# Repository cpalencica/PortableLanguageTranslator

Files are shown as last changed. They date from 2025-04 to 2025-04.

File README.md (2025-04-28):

# Portable Language Translator - Engineering Addendum

This document serves as knowledge transfer guide for any potential future teams working on the Portable Language Translator project. It outlines the current state of the project, technical challenges, implementation details and known issues to assist in understanding and further devloping this system.

## Project Overview
The Portable Language Translator is a wearable device that enables real-time translation between spoken languages (currently English, Spanish, Korean) and basic American Sign Langauge (ASL) gestures. The system uses a Raspberry Pi 5, camera, microphone, touch screen and speakers housed in a 3D-printed enclosure with shoulder straps for portability.

## Core Functionality
- **Speech-to-Speech Translation:** Translates between English, Spanish and Korean using Google Cloud APIs
- **ASL Gesture Recognition:** Recognizes 5 ASL gestures ("Hello", "Thank You", "Bathroom", "Help", "Yes") and converts them into speech
- **Two-way Communication:** Enables conversation between ASL users and non-signers

## Repository Structure
This repository is organized into three main folders:
- **sw (Software):** Contains all the software-related code, scripts and documentation. A detailed `README_SOFTWARE.md` specific to the software components can be found inside this folder.
- **hw (Hardware):** Contains all the hardware-related files, schematics and documentation. The hw folder includes its own `README_HARDWARE.md` with hardware-specific details.
- **fw (Firmware):** Contains firmware code and documentation. The fw folder also has a dedicated `README_FIRMWARE.md` explaining the firmware components.

Each subfolder provides its own README that describes the specific components and instructions that relate to that part of the Portable Language Translator.

## Technical Architecture
### Hardware Components
- Raspberry Pi 5
- USB 2.0 Camera
- USB Microphone
- USB Speaker
- Touch Screen
- 5000 mAh battery pack
- 3D-printed enclosure

### Language Translation Pipeline
1. **Audio Capture:** Using USB microphone and WebRTC VAD for speech detection
2. **Speech-to-Text:** Google Cloud Speech-to-Text API
3. **Translation:** Google Cloud Translation API
4. **Text-to-Speech:** Google Cloud Text-to-Speech API
5. **Audio Output:** Through USB speakers

### ASL Recognition Pipeline
1. **Video Capture:** Using USB camera with OpenCV
2. **Hand Landmark Detection:** Using MediaPipe
3. **Gesture Classification:** LSTM model converted to TFLite
4. **Speech Synthesis:** Outputs recognized gesture as spoken words

### User Interface
- Built with PyQt5
- Three main tabs: Translation, WiFi Connection, Settings
- Volume controls and mode toggle (physical buttons)

## Getting Started
### Prerequisites
- Internet Connection (required for cloud based translation APIs)
- Python 3.9+ environment
- Power Source for the Raspberry Pi 5 (exterior battery pack)

### Initial Setup
1. **Power on:** Press the power button on the battery pack once
2. **Connect to WiFi:** Navigate to WiFi tab and connect to a network
3. **Configure Settings:** Set your preferred language options in the Settings tab
4. **Start Translation:** Return to the Translation tab to begin using the device

### Operating Modes
- **Speech Translation Mode**: Speak and the device will detect the language being spoken and translate bidirectionally with the base language set in the Settings tab.
- **ASL Mode:** Press the button on the left side to switch modes. The camera feed will display and detect ASL gestures.

## Technical Gotchas and Known Issues
### Critical Information
- **Internet Dependency:** The speech translation functionality requires an internet connection to use Google Cloud APIs. ASL recognition works offline but with limited vocabulary.
- **Battery Life Constraints:** The device runs for approximately 3.125 hours on a full charge.
- **ASL Recognition Limitations:** The current implementation only recognizes 5 gestures with 80%+ accuracy. Optimal detection distance is 0.67 to 1 meter from camera and the performance degrades significantly past this range.
- **Speech Recognition Limitations:** Works best 0.5-1 meters from microphone and converstational volume is required for reliable operation. Background noise can impact performance.
- **Heat Management:** The Raspberry Pi 5 can get hot during extended use.
- **Water/Moisture Vulnerability:** The device is not waterproof or water-resistant. Keep away from liquids.

### Development Challenges
When extending this project, be aware of these challenges we encountered:
- **LSTM Model Optimization:** Converting the TensorFlow model to TFLite required balancing accuracy with performance. Further optimization might be possible.
- **Latency Management:** Speech translation introduces variable latency (0.34-1.90 seconds) depending on phrase length. ASL recognition has approximately 2.5 seconds of latency.
- **Model Training:** During our second prototype testing, the ASL recognition model was trained on a limited dataset. Ensure there is a significant amount of data for higher recognition accuracy.

### Future Improvements
Based on our experience, these areas would benefit from further development:
- **Expanded ASL Vocabulary:** The current system only recognizes 5 gestures. Training the model on more gestures would increase utility.
- **Offline Translation:** Implementing an on-device translation library would eliminate the need for an internet connection.
- **Environmental Robustness:** Adding more noise cancellation for the microphone and improving camera performance in varied lighting conditions.

## Debugging Tips
### Common Issues and Solutions
- **Device Won't Power On:** Check battery charge level on the external battery pack and verify connections between battery and Raspberry Pi.
- **No Audio Output:** Check volume settings and verify speaker connection.
- **Camera Not Working:** Check USB connection.
- **Slow Performance:** Check CPU temperature and verify proper cooling for the Raspberry Pi 5.

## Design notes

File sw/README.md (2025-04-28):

# Software Modules Overview

## main.py

### Overview
Main.py file serves as the main controller for the Portable Language Translator. It integrates ASL gesture recognition, speech processing, and hardware control. It uses TensorFlow Lite for ASL recognition, MediaPipe for pose detection, and a custom class that uses Google Cloud for speech processing. The system operates in two modes: ASL and Speech. 

### Core Framework and Dependencies
The system integrates multiple key libraries including TensorFlow, MediaPipe, OpenCV, and PyQt5 to create a custom solution to automatically translate speech and detect ASL gestures. The code uses multiple threads to handle simultaneous ASL processing, inference, and translation operations.

### ASL Gesture Recognition Components
The ASL recognition system uses MediaPipe to get hand and pose landmarks and a TensorFlow Lite Long Short Term Memory model for gesture classification. Key functions include:

```python
def tflite_predict(sequence):
    """Run TFLite inference on a given input sequence."""
    sequence = np.expand_dims(sequence, axis=0).astype(np.float32)
    interpreter.set_tensor(input_details[0]['index'], sequence)
    interpreter.invoke()
    return interpreter.get_tensor(output_details[0]['index'])[0]

def mediapipe_detection(image, model):
    """Runs MediaPipe Holistic on a frame and returns the drawn image and results."""
    image_rgb = cv2.cvtColor(image, cv2.COLOR_BGR2RGB)
    image_rgb.flags.writeable = False
    results = model.process(image_rgb)
    image_rgb.flags.writeable = True
    drawn_frame = cv2.cvtColor(image_rgb, cv2.COLOR_RGB2BGR)
    return drawn_frame, results
```

### Mode Control
The system operates in two modes, ASL and Speech, with a physical button to toggle between them. The change_mode() function handles the transition between modes:

```python
def change_mode():
    global mode, cap, sequence, predictions, sentence
    # Flush ASL buffers/queues
    while not sequence_queue.empty():
        sequence_queue.get_nowait()
    while not result_queue.empty():
        result_queue.get_nowait()
    sequence.clear()
    predictions.clear()
    sentence.clear()
    
    cv2.destroyAllWindows()
    if mode == "ASL":
        mode = "SPEECH"
        speech_mode_logic()
        if cap is not None:
            cap.release()
            cap = None      
        print("Mode changed to SPEECH")
        translator_device.reset()
        translator_device.active = True
        shared.ui_mode = "TEXT"
    else:
        mode = "ASL"
        with open(file_path, 'w') as file:
            pass  # clear the file contents
        asl_mode_logic()
        if cap is None:
            cap = cv2.VideoCapture(0)
        print("Mode changed to ASL")
        shared.ui_mode = "CAMERA"

    shared.mode = mode
```

### Multithreading
The system has several concurrent threads for processing:
ASL Inference Thread - Processes gesture sequences asynchronously
Translator Thread - Handles speech recognition and translation
ASL Processing Thread - Manages camera input and ASL detection pipeline

```python
asl_thread = threading.Thread(target=inference_worker, daemon=True)
asl_thread.start()

translator_thread = threading.Thread(target=translator_device.start, daemon=True)
translator_thread.start()

asl_proc_thread = threading.Thread(target=asl_processing_loop, daemon=True)
asl_proc_thread.start()
```

### Hardware Integration
The code interfaces with physical buttons for mode control and volume adjustment:
```python
button_mode = Button(PIN_MODE, pull_up=True, bounce_time=0.2)
button_up = Button(PIN_UP, pull_up=True, bounce_time=0.2)
button_down = Button(PIN_DOWN, pull_up=True, bounce_time=0.2)

button_mode.when_pressed = change_mode
button_up.when_pressed = volume_up
button_down.when_pressed = volume_down
```

### Main Processing Loop
The ASL processing loop continuously captures frames, processes them through MediaPipe, extracts keypoints, and performs inference:

```python
def asl_processing_loop():
    # Processes ASL gestures in real-time using the camera
    # Extracts pose landmarks, performs inference, and updates UI elements
    # Maintains a history of predictions to ensure consistent recognition
    # Synthesizes speech when a complete gesture sequence is detected
```

### Application Entry Point
The main function initializes the UI component and manages the application lifecycle:

```python
if __name__ == "__main__":
    file_path = "als_speech_audio_transcription.txt"
    with open(file_path, 'w') as file:
        pass  # clear the file contents

    app_qt = QApplication(sys.argv)
    window = MainWindow(file_path, translator_device)
    window.show()
    try:
        exit_code = app_qt.exec_()
    except KeyboardInterrupt:
        exit_code = 0
    finally:
        cleanup()
    sys.exit(exit_code)
```

### shared.py
This file is used as a place for global variables that need to be accessed across different modules in the Portable Language Translator project. This allows for easy state management between the different components.

### Key Variables
- latest_frame
    - Stores the most recently captured camera frame from the ASL processing loop
    - Used by the UI to display the camera feed with pose landmarks
    - Initially set to None until the first frame is captured
- mode
    - Tracks the current operating mode of the device
    - Can be either "SPEECH" (for voice translation) or "ASL" (for sign language recognition)
    - Initially set to "SPEECH" as the default mode
- ui_mode
    - Controls what content should be displayed in the UI
    - Can be "CAMERA" (showing the camera feed with pose detection) or "TEXT" (showing translated text)
    - Used by TabularUI to determine which widget to display

## translator_device.py
This file creates a TranslatorDevice class with useful functionalities surrounding audio transcription and translation. Some important functions are highlighted below:

### `__init__`
In the class initialization, many settings are set and can be customized. Specifications on audio sample rates, voice sensitivity, possible languages, voice settings, and thread and client setup are done here.

### VAD_collector
The class used a VAD (voice activity detection) library to control the conversation flow. Audio is processed in chunks and voice is detected in each chunk using the VAD library whose sensitivity can be changed in the initialization. The VAD waits until it detects a chunk with voice and then ends and sends the audio stream once there is a chunk detected without voice activity to better match conversation flow.

### transcribe_and_translate
This is the main functionality of the class. This function takes in the audio chunk, sends it to Google Cloud API to detect the language from the list of possible languages and transcribe the audio. Once that is done it translates the text and sends back the result where it is then taken by other functions to create the audio playback of the translated text.

### set_settings
This function is used to set the base language of the device and the voice gender preferences.

### start
This function is used the start the audio input stream.

### listen_and_save_transcription
This function is used by the ASL mode to take in audio and save the transcribed text to a file to be later displayed on screen.

## virtual_keyboard.py
virtual_keyboard.py creates a class called VirtualKeyboard. This is used in a section of the UI, specifically in the second tab for WiFi Connectivity. This is essentially done by creating a Qwidget object that organizes a grid of push buttons that contain relevant keyboard inputs for entering WiFi credentials. On pressing a button it will respond by populating the relevant textbox for entering credentials. The relevant keyboard declaration and creation is highlight below.

```python
self.keys = [
            ['1', '2', '3', '4', '5', '6', '7', '8', '9', '0'],
            ['q', 'w', 'e', 'r', 't', 'y', 'u', 'i', 'o', 'p'],
            ['a', 's', 'd', 'f', 'g', 'h', 'j', 'k', 'l', '←'],
            ['↑', 'z', 'x', 'c', 'v', 'b', 'n', 'm', '␣']
        ]

        keyboard_frame = QFrame()
        keyboard_frame.setStyleSheet("background-color: #333; border-radius: 10px; padding: 10px;")
        grid_layout = QGridLayout()

        for row_idx, row in enumerate(self.keys):
            for col_idx, key in enumerate(row):
                btn = QPushButton(key.upper() if self.caps_lock else key)
                btn.setFixedSize(50, 50)
                btn.setStyleSheet(self.get_button_style(key))
                btn.clicked.connect(lambda checked, k=key: self.key_pressed(k))
                grid_layout.addWidget(btn, row_idx, col_idx)
                self.buttons[key] = btn
```

## TabularUI.py
Our TabularUI.py script is in charge of setting up our user interface. Specifically we have our code organized as three seperate tabs, each of which has its own functionality. Tab 1 is in charge of general translation functionality. Tab 2 is in charge of WiFi connectivity. Tab 3 is used for settings control. All initialization and setup is done in the class method initUI(self).

``` python
def initUI(self):
        self.tabs = QTabWidget()
        self.tabs.setStyleSheet("""QTabWidget::pane { border: 1px solid #aaa; background: #ddd; }
                                  QTabBar::tab { padding: 6px; font-size: 10px; background: #eee; color: black; border: 1px solid #aaa; }
                                  QTabBar::tab:selected { background: #ccc; }""")
       
        # Create Tabs
        self.tab1 = QWidget()
        self.tab2 = QWidget()
        self.tab3 = QWidget()
       
        # Add tabs to the QTabWidget
        self.tabs.addTab(self.tab1, "Translation")
        self.tabs.addTab(self.tab2, "Wi-Fi")
        self.tabs.addTab(self.tab3, "Settings")
       
        # Set up layouts for each tab
        self.setupTab1()
        self.setupTab2()
        self.setupTab3()
       
        self.setCentralWidget(self.tabs)
```

1. First Tab (Translation)
The first tab is comprised of a few components to enable translation functionality. It consists of a status label, video label, a text editor. The class method setupTab1() sets up the Widgets such that the status label shows the current functional mode of the device, either "SPEECH" or "ASL". The video label will show the live camera feed when in ASL mode, and the text editor will give text translations in both user modes.

2. Second Tab (WiFi Connectivity)
The second tab setups various components to allow the device to connect to internet using the class method setupTab2(). It initializes the VirtualKeyboard class and then creates various textboxes to allow the user to enter relevant SSID and passwords for the internet they are trying to connect to.

3. Third Tab (Settings)
The third and final tab setups widgets for a volume indicator, language mode buttons, voice settings dropdown. This is created using the setupTab3() method.

## model.tflite
This file is a Long Short Term Memory model based off of TensorFlow that has been converted to TensorFlow Lite to be used forASL recognition. This model is designed to recognize a predefined set of ASL gestures in real time from video input. 

## Convert.py
This file is used to convert the keras model into a smaller tflite file for deployment.

## PLT.ipynb
This notebook file contains the process for building and training the Long Short Term Memory (LSTM) neural network that allows for ASL recognition. It has data collection, preprocessing, model creation, training, and evaluation.

### Key Components

#### Environment Setup
First install necessary dependencies and import libraries
```
!pip install tensorflow opencv-python mediapipe scikit-learn matplotlib
```
```python
import cv2
import numpy as np
import os
import mediapipe as mp
import matplotlib.pyplot as plt
```

#### Data Collection Pipeline
Data collection is done with multiple workflows:

##### MediaPipe Setup
```python
mp_holistic = mp.solutions.holistic # Holistic model
mp_drawing = mp.solutions.drawing_utils # Drawing utilities
```

##### Helper Functions
mediapipe_detection: Processes video frames through MediaPipe
draw_styled_landmarks: Visualizes pose and hand landmarks
extract_keypoints: Converts MediaPipe results to feature vectors

##### Data Structure Definition
The actions array contains the gestures the ASL model will collect data for and train. Each training video will be 30 frames per sequence. 
```python
# ASL gestures to recognize
actions = np.array(['hello', 'thanks', 'nothing', 'help', 'yes', 'bathroom'])

# 30 frames per sequence
sequence_length = 30
```

##### Data Collection Loop
The notebook will record and collect data by:
Creates directories for each gesture
Captures 30-frame sequences for each example
Extracts pose and hand landmarks using MediaPipe
Saves landmark data as NumPy files
Provides visual feedback during recording
This will create a dataset with the following structure:
```
MP_Data/
  hello/
    0/
      0.npy, 1.npy, ..., 29.npy
    1/
      0.npy, 1.npy, ..., 29.npy
    ...
  thanks/
    ...
```

#### Data Preprocessing
After data has been collected, it will then be processed for model training:
```python
# Load sequences and create labels
sequences, labels = [], []
for action in actions:
    for sequence in np.array(os.listdir(os.path.join(DATA_PATH, action))).astype(int):
        window = []
        for frame_num in range(sequence_length):
            res = np.load(os.path.join(DATA_PATH, action, str(sequence), f"{frame_num}.npy"))
            window.append(res)
        sequences.append(window)
        labels.append(label_map[action])

# Convert to numpy arrays and one-hot encode labels
X = np.array(sequences)
y = to_categorical(labels).astype(int)

# Split into train/test sets
X_train, X_test, y_train, y_test = train_test_split(X, y, test_size=0.05)
```

#### LSTM Model Architecture
The model will use a stack LSTM architecture:
```python
model = Sequential([
    Input(shape=(30, 258)),
    LSTM(64, return_sequences=True, activation='tanh'),
    LSTM(128, return_sequences=True, activation='tanh'),
    LSTM(64, return_sequences=False, activation='tanh'),
    Dense(64, activation='relu'),
    Dense(32, activation='relu'),
    Dense(actions.shape[0], activation='softmax')
])
```

#### Training Process
The LSTM model is trained with:
```python
model.compile(optimizer='Adam', loss='categorical_crossentropy', metrics=['categorical_accuracy'])
model.fit(X_train, y_train, epochs=100, callbacks=[tb_callback])
```

#### Model Evaluation
Once the LSTM model has been trained, the model performance is evaluated with:
```python
yhat = model.predict(X_test)
ytrue = np.argmax(y_test, axis=1).tolist()
yhat = np.argmax(yhat, axis=1).tolist()

# Confusion matrix for detailed performance analysis
multilabel_confusion_matrix(ytrue, yhat)

# Overall accuracy
accuracy_score(ytrue, yhat)
```

#### Model Export
Once the model has been trained and evaluated it is saved to be used later in the main application.
```python
model.save(‘model.keras’)
```

# Flow Chart
The flow chart shows the dependencies between different Python modules:
- main.py depends on:
    -  TabularUI.py - UI for the application
    -  model.tflite - LSTM model for ASL recognition
    - translator_device.py - File for speech translation and processing
- TabularUI depends on:
    - virtual_keyboard.py - Keyboard UI for the wifi section
    - shared.py - Global variables for state manegement
    - translator_device.py - Allows the UI to control translation functionality
- translator_device.py depends on:
    - shared.py - Global variables for state manegement
- model.tflite requires:
    - convert.py - Converts the model.keras to model.tfile
    - PLT.ipynb - Collects and trains data for the LSTM model.keras

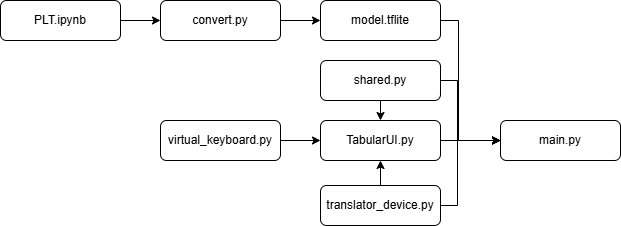
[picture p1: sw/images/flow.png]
Alternative text


# Dependencies
Dependencies for this project are listed below and can be found in requirements.txt.

### Core ML & Computer Vision
- Python 3.9+ with TensorFlow 2.16.1
- MediaPipe 0.10.14
- OpenCV-Python 4.10.0.84
- NumPy 1.26.4

### Audio Processing
- SoundDevice 0.5.1
- webrtcvad 2.0.10
- PyDub 0.25.1

### Google Cloud Services
- google-cloud-speech 2.31.0
- google-cloud-texttospeech 2.25.0
- google-cloud-translate 3.20.0
- protobuf (latest compatible)

### GUI
- PyQt5 5.15.9

### Raspberry Pi Hardware Interface
- gpiozero 2.0
- RPi.GPIO 0.7.1
- pigpio 1.78

### Additional Python Libraries
- matplotlib 3.9.2
- scikit-learn 1.5.2
- Pillow 11.1.0
- pynput 1.7.7
- pygame 2.5.2

# Google Cloud
A Google Cloud Platform account is necessary for the functionality of the software and the device. Once the account is created, the steps below will show you how to set it up to work with the code:

###  Step 1: Set Up Google Cloud Platform (GCP)

The Translator Device uses three Google Cloud APIs:
- **Speech-to-Text API** (speech recognition)
- **Text-to-Speech API** (speech synthesis)
- **Translation API** (language translation)

#### Create a GCP Project
1. Go to the [Google Cloud Console](https://console.cloud.google.com/).
2. Click **"Create Project"**.
3. Name your project (e.g., `Optimum Translator Device`) and click **Create**.
4. After creation, **select your project** from the top menu.

### Step 2: Enable Required APIs
1. In the left menu, go to **"APIs & Services > Library"**.
2. Enable the following APIs:
   - **Cloud Speech-to-Text API**
   - **Cloud Text-to-Speech API**
   - **Cloud Translation API**

### Step 3: Create Service Account and Credentials
1. Navigate to **"IAM & Admin > Service Accounts"**.
2. Click **Create Service Account**.
3. Enter a name like `translator-device-sa` and click **Create and Continue**.
4. Grant the service account the **"Project > Owner"** role (can be restricted later).
5. Click **Done**.

### Step 4: Create a key
1. Select the newly created service account.
2. Go to the **"Keys"** tab.
3. Click **Add Key > Create New Key**.
4. Choose **JSON** format.
5. Download and securely store the `.json` key file.

### Step 5: Set the Environment Variable
Set the environment variable to tell your code where the credential file is.

Edit this line in translator_device.py:
```python
os.environ['GOOGLE_APPLICATION_CREDENTIALS'] = '/path/to/your/credentials-file.json'
```

# Installation
## Main Software 
In order to install the project software stack from scratch, download the the files from the github repository on the microcontroller of your choice, i.e Raspberry Pi 5. Install the dependencies with:
```
pip install -r requirements.txt
```
Finally to start the application, run:
```
python3 main.py
```

## Data Collection and Training
If you would like to add or collect your own data, run the PLT.ipynb notebook and go through the cells. Once you have collected your data and trained your model, run the convert.py file to convert the .keras model to a .tflite file.

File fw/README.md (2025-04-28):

# Firmware

## Summary
This folder contains the implementation for two relevant firmware components of the project. For one, our project needs to control the audio system so that users can hear translations from the speaker. Secondly, we have the code for implementing button control over the volume and mode toggling. Althought the relevant code already exists in everything.py, we still want to highlight the firmware components seperately in its own section. 

### Volume Control (volume_control.py)
volume_control.py takes advantage of os calls. Specifically it uses amixer to control increases and decreases in the volume using the functions calls to increase_volume() and decrease_volume. The script also runs an example under adjust_volume() to test modifying the volume.

### Button Control (button_control.py)
button_control.py using the gpiozero library to implement hardware interrupts. The buttons are pulled high via an internal pull up resistor. The other end of the buttons are connected to ground such that the software waits for the button to be pressed for the state to be pulled down to ground. Specifically, this script sets up three hardware interrupts using the following portion of code below. These lines of code setup the hardware interrupt parameters and attach a function that happens on event trigger.

``` python
button_mode = Button(PIN_1, pull_up=True, bounce_time=0.2)
button_up = Button(PIN_2, pull_up=True, bounce_time=0.2)
button_down = Button(PIN_3, pull_up=True, bounce_time=0.2)

button_mode.when_pressed = change_mode
button_up.when_pressed = volume_up
button_down.when_pressed = volume_down
```

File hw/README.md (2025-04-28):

# Hardware

## CAD Designs
All relevant drawings are included in the cad_files directory. It includes all the stl files but also all images of the drawings. The 3D prints work together to make one final encasing. Please click on the STL links to view and 360 design of the different encasing components.

<p align="center">
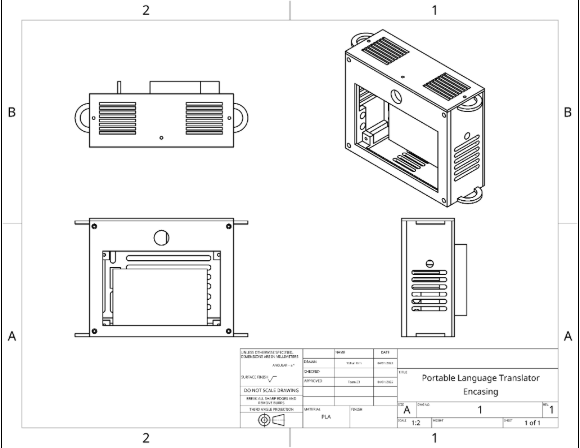
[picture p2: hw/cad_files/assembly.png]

Bill of Materials
</p>

Specifically, we created 4 relevant components to the final encasing. They includes a backplate, frontplate, lid, and a mount.

#### Mount
The mount acts as the basis for the encasing. It permits the mounting of all relevant components of the device. Specifically there are specific locations for the camera, display, and Raspberry Pi to interface with. 
* [Mount Visual](./cad_files/Mount_3D_Drawing.pdf) 
* [Mount STL File](./cad_files/Display_Mount.stl)

#### Backplate
The backplate serves as a cover for the internal electrical components. Despite being a cover it provides for open grating such that the device can properly ventilate hot air generated from the Raspberry Pi. Additional it acts as mounting point for the battery back. 
* [Backplate Visual](./cad_files/Back_Plate_3D_Drawing.pdf)
* [Backplate STL File](./cad_files/Back_Plate.stl)

#### Frontplate
The frontplate is used to mount the display in place while making a flush finish for the camera and display. 
* [Frontplate Visual](./cad_files/Front_Plate_3D_Drawing.pdf)
* [Frontplate STL File](./cad_files/Front_Plate.stl)

#### Lid
The lid is used to cover the sytem speakers with some grating to allow clear audio to be output from the device.
* [Lid Visual](./cad_files/Mount_3D_Drawing.pdf)
* [Lid STL File](./cad_files/Display_Mount.stl)

## Primary Hardware Components
The main hardware components to consider include a USB camera, speaker, and camera, buttons, Raspberry Pi 5, touchscreen display, and battery pack.

#### Raspberry Pi 5 and Active Cooler
The Raspberry Pi 5 acted as the primary processing device. It handled connectiving to internet and communicating with the Google Translate API. Furthermore it connects to all relevant peripherals of the device including the USB devices, buttons, and display in order to orchestra all relevant interactions.

<p align="center">
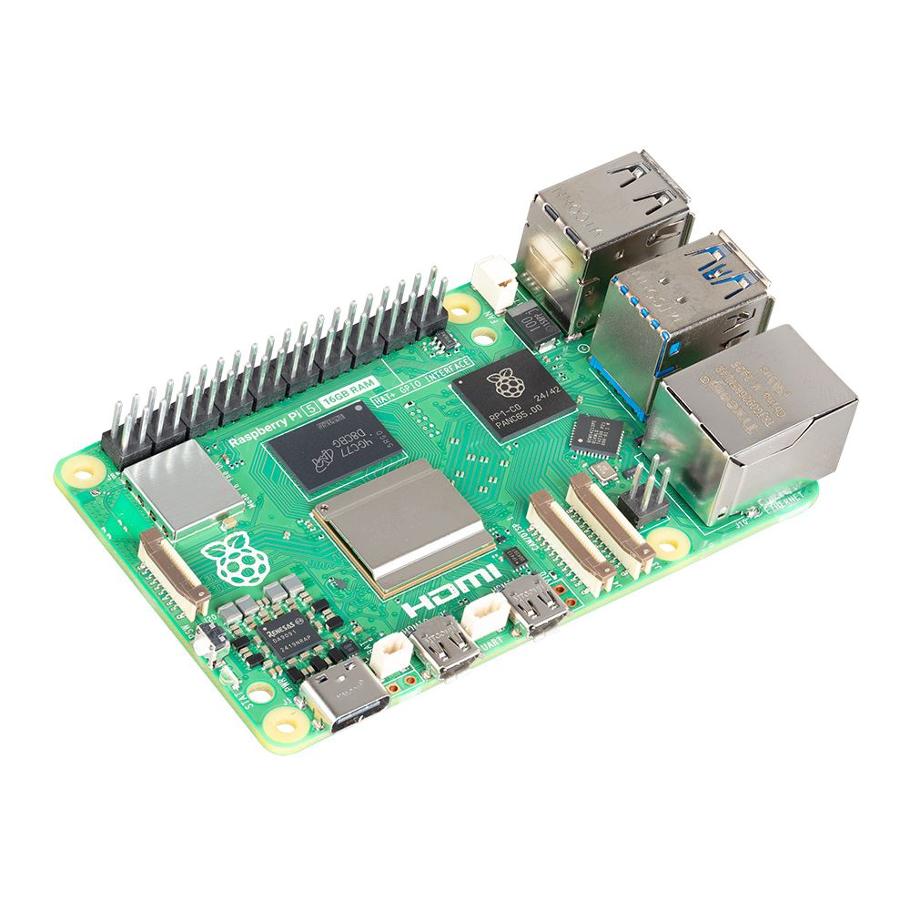
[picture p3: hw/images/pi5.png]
  
  <br> <!-- line break -->
  <b>Raspberry Pi 5</b>
</p>

Despite observing high performance guarantees from the Raspberry Pi 5, we noticed high temperatures from the system. Due to this we invested in a cooling system for the device in the form of the Raspberry Pi 5 Active Cooler.

<p align="center">
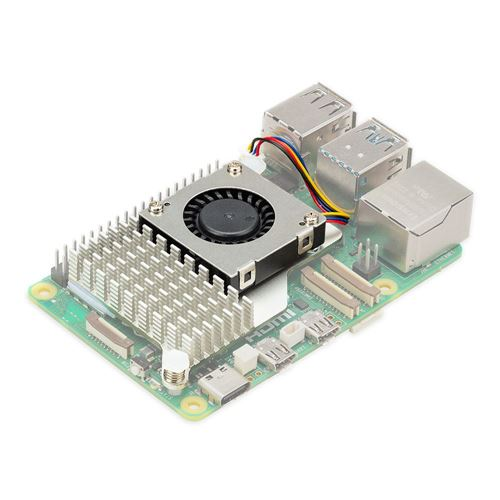
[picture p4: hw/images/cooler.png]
  
  <br> <!-- line break -->
  <b>Active Cooler for Raspberry Pi 5</b>
</p>

#### USB Camera
The USB Camera is directly connected to the USB hub on the Raspberry Pi 5. It mainly acts as an input feed to be fed into our ASL translation model.

<p align="center">
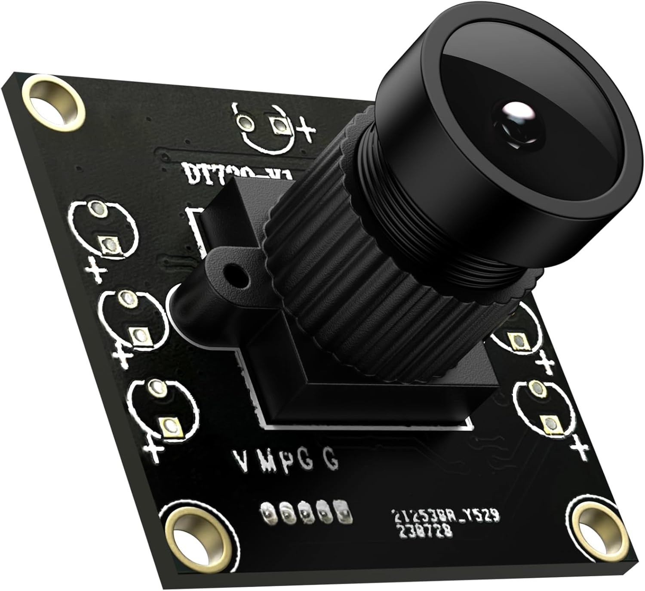
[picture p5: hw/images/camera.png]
  
  <br> <!-- line break -->
  <b>USB Camera</b>
</p>

#### USB Speaker
The USB Speaker is directly connected to the USB hub on the Raspberry Pi 5. It acts as an output medium for translations.

<p align="center">
  
  <br> <!-- line break -->
  <b>USB Speaker</b>
</p>

#### USB Microphone
The USB Microphone is directly connected to the USB hub on the Raspberry Pi 5. It mainly acts as an input feed to be fed into our Language Translation Software.

<p align="center">
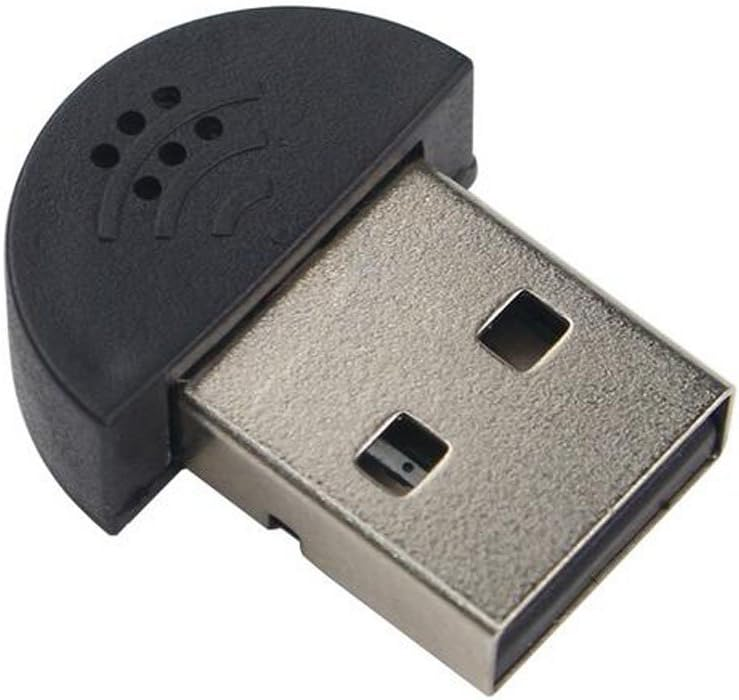
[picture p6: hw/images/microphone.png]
  
  <br> <!-- line break -->
  <b>USB Microphone</b>
</p>

#### Buttons
The buttons are setup with hardware interrupts in order to control volume and mode toggling. These are connected to GPIO Pins 4, 17, and 27. Specifically these buttons are pulled high via an internal pull up resistor. When the software detects that the state has been pulled to GND, it will triggered the attached interrupt event.

<p align="center">
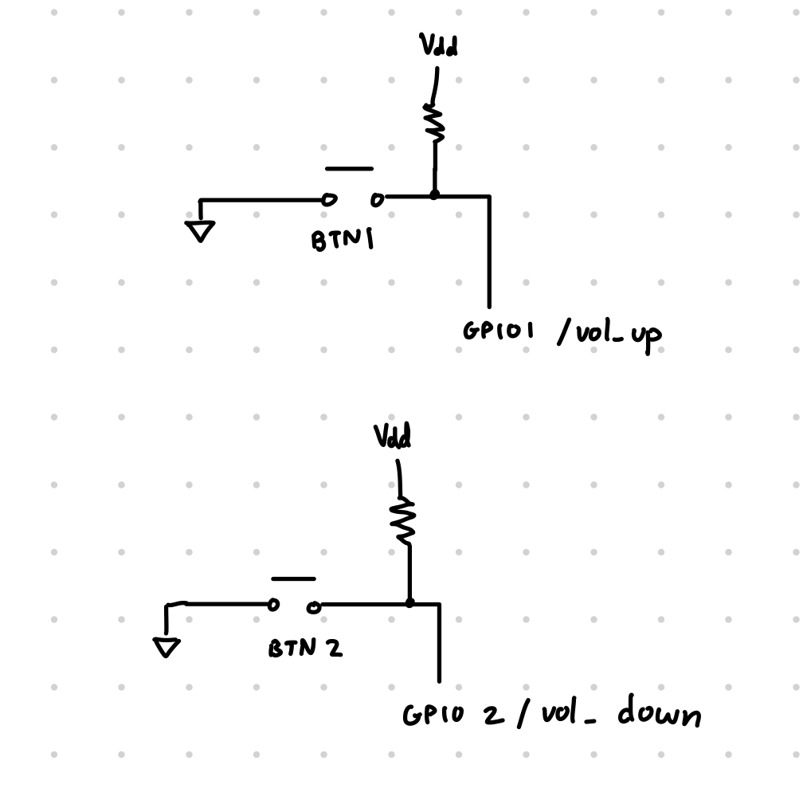
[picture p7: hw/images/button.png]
  
  <br> <!-- line break -->
  <b>Button Implementation</b>
</p>

#### Touchscreen Display
The touchscreen display is power and connected via a DSI cable. It allows for a direct connection to the Pi homescreen and allows viewing of our User Interface.

<p align="center">
  
  <br> <!-- line break -->
  <b>Touchscreen</b>
</p>

## System Inside Enclosure
Below we have the internals of the system with the enclosure. The Raspberry Pi can be seen directly attached to the touchscreen. From the Raspberry Pi we also observe the various different peripherals connecting from it including the various USB devices and the button coming from the gpio pins. The speakers are enclosed by some styrofoam such as to cushion the vibrations to reduce any impacts to the rest of the device. We also observe that the active cooler points out of the device such as to dispel any hot hair generated by the microcontroller. 

<p align="center">
  
  <br> <!-- line break -->
  <b> System Internals </b>
</p>

Finally, the speakers can be seen directly below the upper lid where the grating allows for the audio to come out clearly.
<p align="center">
  
  <br> <!-- line break -->
  <b> System Audio </b>
</p>

## Device Setup
In order to setup the device we need to consider how to interface the various components with the different parts of our encasing. 

1. We'll start off with the Raspberry Pi. We can mount the Raspberry Pi directly to the touchscreen using the screws that come with the display. 

2. Once this is done we can now connect all the relevant USB devices in any order. (Note: We decided to strip and resolder our cables in order to make the length more manageable to be capable of fitting with the encasing). 

3. We can now connect our buttons to our GPIO pins. This assumes that all your buttons have been appropriately soldered to some female cables to interface with the GPIO pins on the Raspberry Pi 5. The mode toggling button should be attached to GPIO pin 4, while the volume up and volume down buttons should be attached to pins 17 and 27, respectively.

4. We can now place all components directly into place within the encasing. For reference all screws used are M2.5. This means we can place the speaker at the top of the encasing via a tight fit. The Raspberry Pi and touchscreen can be mount directly to the mount print by screwing the display in. The same can be done with the camera, it can be screwed into place in the slot at the top of the mount. Finally, the buttons can be attached to the holes available on either end with the threads built into the physical button. With everything in place we can attach the backplate to cover up the device. Now the top lid can be glued in place to cover up the speakers. Finally, the front plate can be screwed in as well onto the mount.

## Bill of Materials (BOM)
<p align="center">
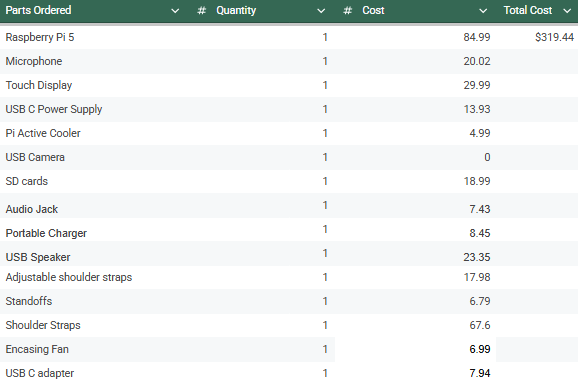
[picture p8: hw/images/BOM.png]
  
  <br> <!-- line break -->
  <b>Bill of Materials</b>
</p>

Above we see the list of necessary components for the project totaling to $319.44. 

## Vendors and Relevant Data Sheets
Below we have included all relevant links for the parts purchased for our device. This includes links to the sites where we purchased from but also relevant documentation cites for the devices.

Note: For components from Amazon most documentation and specification are already embedded within the amazon link

* Camera [(Amazon)](https://www.amazon.com/dp/B0CLRJZG8D?ref=ppx_yo2ov_dt_b_fed_asin_title) 

* Microphone [(Amazon)](https://www.amazon.com/KISEER-Microphone-Desktop-Recording-YouTube/dp/B071WH7FC6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)

* Speaker [(Amazon)](https://www.amazon.com/HONKYOB-Speaker-Computer-Multimedia-Notebook/dp/B075M7FHM1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)

* Raspberry Pi 5 [(Microcenter)](https://www.microcenter.com/product/688718/product?src=raspberrypi) and [additional documentation](https://www.raspberrypi.com/products/raspberry-pi-5/)

* Raspberry Pi Active Cooler [(Microcenter)](https://www.microcenter.com/product/671930/raspberry-pi-5-active-cooler?src=raspberrypi) and [additional documentation](https://www.raspberrypi.com/products/active-cooler/)

* Touchscreen  [(Amazon)](https://www.amazon.com/Hosyond-Touchscreen-Compatible-Capacitive-Driver-Free/dp/B0CXTFN8K9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)

* Battery Pack [(Amazon)](https://www.amazon.com/SIXTHGU-Portable-Capacity-External-Indicator/dp/B08QHG1SWY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)

## Power Requirements
The main power requirements for our device pertain to the battery pack. The battery pack provided with the design is a 5V, 5000mAh, with a max current draw of approximately 2.4A. Under the highest stress out device consumes approximately 1.6A of current. With these considerations at max performance our device would last 3.125 hours. 

The user is free to incorporate their own battery pack if they desire to achieve a longer battery life. As long as the battery pack can properly supply power to the Raspberry Pi with a voltage of 5V, and a minimum current of 1.6A any other power source can be used to drive the device. A wall plug would also be sufficient in cases where the user doesn't plan on moving the device.

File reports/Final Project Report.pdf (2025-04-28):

# Boston University Electrical & Computer Engineering

EC 464 Senior Design Project

## Final Project Test Report

Portable Language Translator

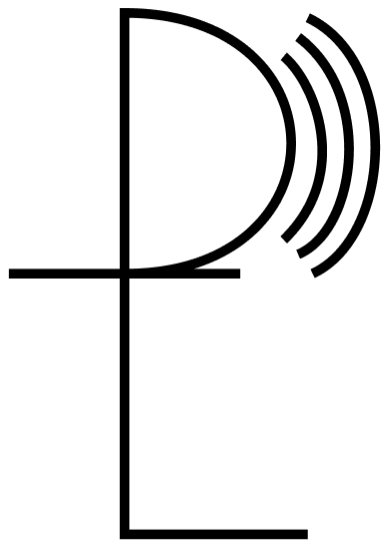
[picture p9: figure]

By

Team 23

Portable Language Translator

Team Members

Yohan Kim yohank@bu.edu
Ryan Liao ryanliao@bu.edu
Cristian Palencia cris0211@bu.edu Andrew Nguyen aynguyen@bu.edu

For the hardware setup we have a Raspberry Pi 5 that interfaces with all the relevant components. Specifically, it interfaces with the following: USB camera, USB speaker USB microphone and a touch display all of which are mounted throughout the 3D printed encasing. The Raspberry Pi will be connected to the user’s phone hotspot using 1 of 3 UI tabs where a user can select their internet and insert their password through a virtual keyboard displayed on the touch display.
For the language translation, a dedicated UI tab allows users to configure settings for the language translation, such as, base language and voice gender before the translation starts. One device is used for the conversation. The users must wait for the translation and playback to fully finish before beginning the next phrase. The program captures audio from the USB microphone, splits it into chunks and uses voice activity detection software to determine if someone is speaking. Once it detects no speech, it sends the audio file to the google cloud for the transcription, translation, and finally text-to-speech. The audio file is sent back to the program which it plays from the system’s speaker and to display the translated text on the translation UI tab.
For the ASL gesture detection and prediction, the external camera (USB 2.0 Camera) will record a live video stream and the script will initialize this video feed with OpenCV. First processing camera frames is done with Mediapipe’s hand landmarks model to extract hand landmarks and then grouping these landmarks from the last 30 frames into a sequence. This sequence is fed into our LSTM (Long Short Term Memory) model that outputs the probability for each gesture. When a specific gesture’s confidence is greater than the threshold value, that gesture will be then chosen as the detected gesture. An asynchronous thread handles this inference process, ensuring that consistent and confident predictions are added to a running sentence, which is eventually converted into speech for translation. Once the sentence is done playing, the script will then listen for the audio and save the transcription in a .txt file where it will be displayed in the UI. Then the script will go back to detecting ASL gestures and the cycle will restart.

Measurements and Data:

Language tests
Accuracy: We wanted to collect some data to demonstrate the accuracy and functionality of our language translation code. The data collected in Tables 1-6 below demonstrates different translation paths such as English - Korean and Korean - Spanish. For each row we notice: “Phrase Said” being the words spoken by the user, “Phrase Recorded” being the words picked up by the software, “Translated Phrase” being the final translation that is determined and outputted by the software. Under “Errors?” we write the degree to which the translation and transcription were incorrect. Transcriptions define whether the actual translation was wrong while the Translation then describes whether given a transcription we were able to correctly output it. As an additional note this is the same data as prototype test one and two since we should observe the same performance as long as the microphone on the Raspberry Pi is capable of picking up the intended phrase.
Phrase Said | Phrase Recorded | Translated Phrase | Errors
Hello, how are you? | hello how are you | 안녕하세요. 어떻게 지내세요 | Transcription: no errors Translation: no errors
Can I get a large coffee with two sugars and no milk, please? | can I get a large coffee with Two Sugars and no milk | Two Sugars와 우유 없이 큰 커피 한 잔을 마실 수 있나요? | Transcription: no errors Translation: no errors
Excuse me, how do I get to the nearest train station? | excuse me how do I get to the nearest train station | 실례합니다. 가장 가까운 기차역까지 어떻게 가나요? | Transcription: no errors Translation: no errors

Table 1: English - Korean Translation

Phrase Said | Phrase Recorded | Translated Phrase | Errors
Do you have fresh strawberries or are they out of season? | you have fresh strawberries or are they out of season | ¿Tienes fresas frescas o están fuera de temporada? | Transcription: missing word Translation: no errors
Can I try this jacket on in a medium size? | can I try this jacket on in a medium sized | ¿Puedo probarme esta chaqueta en talla mediana? | Transcription: minor error Translation: no errors
What time are we meeting tomorrow for | what time are we meeting tomorrow for | ¿A qué hora nos reuniremos mañana | Transcription: missing word

lunch at the new
restaurant?

lunch at the new para almorzar en el nuevo?

Translation: no errors

Table 2: English - Spanish Translation

Phrase Said | Phrase Recorded | Translated Phrase | Errors
¿Hola, tienes fresas frescas o están fuera de temporada? | Hola tienes fresas frescas o están fuera de temporada | 안녕하세요. 신선한 딸기가 있나요? 아니면 제철이 아니나요? | Transcription: no errors Translation: no errors
¿Puedo probarme esta chaqueta en talla mediana? | puedo probarme esta chaqueta en talla mediana | 이 재킷을 미디엄 사이즈로 입어봐도 될까요? | Transcription: no errors Translation: no errors
¿A qué hora nos reuniremos mañana para almorzar en el nuevo restaurante? | a qué hora nos reunimos mañana para almorzar en el nuevo restaurante | 우리 내일 몇 시에 새 식당에서 점심 먹으러 만나요? | Transcription: no errors Translation: no errors

Table 3: Spanish - Korean Translation

Phrase Said | Phrase Recorded | Translated Phrase | Errors
안녕하세요. 어떻게 지내세요 | 안녕하세요 어떻게 지내세요 | Hola, cómo estás | Transcription: no errors Translation: no errors
우유 없이 설탕 그게 큰 커피 주세요 | 우유 없이 설탕 그게 큰 커피 주세요 | Me gustaría un café grande con dos azúcares y sin leche. | Transcription: no errors Translation: no errors
실례합니다. 가장 가까운 기차역까지 어떻게 가나요? | 실례합니다 가장 가까운 기차역까지 어떻게 가나요 | Disculpe, ¿cómo llego a la estación de tren más cercana? | Transcription: no errors Translation: no errors

Table 4: Korean - Spanish Translation

Phrase Said | Phrase Recorded | Translated Phrase | Errors
신천한 딸기 있나요 아니면 제철이 아니나요 | 신천한 딸기 있나요 아니면 제철이 아니나요 | Are there any fresh strawberries or are they out of season? | Transcription: no errors Translation: no errors

이 재킷을 M 사이즈로 입어봐도 될까요 | 이 재킷을 M 사이즈로 입어봐도 될까요 | Can I try that jacket in size M? | Transcription: no errors Translation: no errors
우리 내일 몇 시에 새 식당에서 점심 먹으러 만날 거야 | 우리 내일 몇 시에 새 식당에서 점심 먹으러 만날 거야 | What time are we meeting for lunch at the new restaurant tomorrow | Transcription: no errors Translation: no errors

Table 5: Korean - English Translation

Phrase Said | Phrase Recorded | Translated Phrase | Errors
Hola, cómo estás | Hola cómo estás | Hello how are you | Transcription: no errors Translation: no errors
¿Puedo tener un café grande con dos azúcares y sin leche por favor? | puedo tener un café grande con dos azúcares y sin leche por favor | can I have a large coffee with two sugars and no milk please? | Transcription: no errors Translation: no errors
Disculpe, come alcanzo llegar al estacion de tren mas cercano? | Disculpe cómo alcanzo a llegar a la estación de tren más cercano | excuse me, how do I get to the nearest train station? | Transcription: minor errors Translation: no errors

Table 6: Spanish - English Translation

Latency: Referring to Table 7 below, we were able to record some measurements for the latency of our software for different sized phrases. For context, the data was collected using English -Spanish translations (English phrase translated into Spanish). In our collected data, latency is measured by the time the untranslated audio is sent to the cloud to when the translated audio playback starts. This was measured by the Python timer method to provide accurate times.

Specifically, as we move down the table we observe that we are testing with larger and larger phrases to test the correlation between different sized phrases and latency.

Since is the same data collected from Prototype Test Two as there have been no changes to improve or worsen latency.

Phrase | Word count | Latency (seconds)
Hello | 1 | 0.34
Hello, how are you? | 4 | 0.59
I would like to have a water please | 8 | 0.64
Where is the nearest hospital? I am having a serious allergic reaction | 12 | 0.83
I always enjoy quiet evenings at home, reading a good book with a cup of tea | 16 | 1.19
Let’s plan a weekend getaway soon. It’s been too long since we all had some fun together outside at the beach | 21 | 1.21
When we moved into the new neighborhood, we didn’t know anyone, but our neighbors were so welcoming. They even brought over cookies and invited us to their backyard barbecue. It’s been a great place to live ever since | 38 | 1.90

Table 7: Latency Measurements - Data collected on the Raspberry Pi for latency for different sized phrases

ASL Test

Accuracy: With our ASL software, we wanted to test whether the model could accurately detect and predict signed gestures when a user attempts to gesture in ASL. Table 8 below demonstrates attempted gestures at different distances, with the outputs indicating whether each gesture was correctly detected.

Gesture | Distance from Camera | Correct?
Hello | .33 meters | True
Hello | .67 meters | True
Hello | 1 meter | True
Bathroom | .33 meters | True
Bathroom | .67 meters | True
Bathroom | 1 meter | False
Thank you | .33 meters | True
Thank you | .67 meters | True
Thank you | 1 meter | True
Help | .33 meters | True
Help | .67 meters | False
Help | 1 meter | True
Yes | .33 meters | True
Yes | .67 meters | False
Yes | 1 meter | True
Table 8: ASL Gesture Translation Data - Table demonstrates how an intended gesture is detected and translated at different distances using our ASL gesture model.

Latency: We also wanted to record measurements for the latency or processing time for the time it takes for the model to process and play the gesture into the speaker. Latency is measured by the time the gesture is detected to when it is finished playing on the speaker. Table 9 demonstrates the difference gestures and then the corresponding latency in seconds.

Gesture | Latency (seconds)
Hello | 2.50
Bathroom | 2.65
Thank you | 2.58
Help | 2.19
Yes | 2.38
Table 9: ASL Latency Measurements - Demonstrates how long it took to process a given gesture and play it on the speaker.

Microphone Test
Functional Distance: In order to test the functional distance of our new microphone, we used a similar testing method compared to last semester. Referencing Table 10, we were able to come up with a scoring guideline for any given audio recording. With this scoring guideline we were then able to test the microphone at different distances and at varying audio levels. Based on the audio recording we would then be able to give it a quality score between 0 and 4 (shown in Table 11). These are the same values as from Prototype Testing Two as there have been no changes to the microphone since then.
Quality Score | Meaning
0 | Inaudible
1 | Muffled and distant
2 | Language can be understood
3 | Clear audio
4 | Perfect audio recording
Table 10: Quality Score Table - Ranking given to an audio recording based on overall quality.
Distance (m) | Whisper | Conversational Speaking | Yelling / Loud Speaking
0.25 | 3 | 4 | 4
0.50 | 2 | 4 | 4
0.75 | 2 | 4 | 4
1 | 1 | 3 | 4
1.25 | 1 | 3 | 4
1.50 | 0 | 2 | 3
1.75 | 0 | 1 | 3
2 | 0 | 0 | 3
Table 11: Microphone Performance - Performance of USB microphone at varying distances and audio levels.

Battery Life
We determined that at max performance the Pi would draw a maximum of 1.6A from an external power supply. With these considerations we purchased a 5000mAh battery that would at max performance would last us 3.125 hours.

Device Wearability / Portability
The dimensions of our device 139.3mm x 51.2mm x 111.5mm and includes shoulder straps such that a user can easily wear the device for translations.

Conclusions:

Language
The accuracy of the transcription and translation is the same as before. This shows that it is still highly accurate even when moved to the Raspberry Pi 5 and into a physical encasing. Even with the minimal errors, any ASL individual reading the transcribed text or other party speaking a different language should be able to understand the meaning of each phrase. The accuracy is also above our minimum expected percentage accuracy of 90%. More importantly is the latency is sufficiently within our range of less than 4 seconds when the software is now moved to the Raspberry Pi 5.

ASL
Over the course of the semester, we continued to build upon our initial LSTM model by significantly expanding our dataset. Compared to the 10 data points per gesture from the second prototype, we now have about 200 data points per gesture and as expected this has led to a significant increase in performance. The model's accuracy has now risen to 80%, showing improvement in our ASL gesture recognition capabilities. This reinforces our confidence in the model’s potential and validates the importance of robust data collection. Although below our original expected accuracy we understand that with even more data points we could only expect to see this performance to continue increasing. Latency remains consistent, with most delays still attributed to the audio playback of translated gestures, rather than the recognition process itself, which continues to perform efficiently even as the model becomes more accurate.

Microphone
One of our requirements of the project is defined by how far someone can be from the device for full translation functionality. The requirement we defined was a distance of one meter away from the device. This requirement was already completed from our previous microphone from last semester. The change came from the desire to implement a more robust system that would be easier to implement into a physical encasing. Additionally, although we met the bare requirements from our microphone last semester we still noticed a lot of room for improvement. From the collected data we see that the microphone works well within our parameters.

Battery Life
Our minimum battery life requirement was 2 hours at max performance. With the currently implemented battery pack, we are able to get an additional hour of battery life. With this in place we can get full use of our device for extended periods of time while being able to recharge the battery pack whenever the device dies.

Device Wearability
Although slightly larger than originally planned, the addition of the straps provides the user with a lot of support to carry the device when needed. The straps provide significant shoulder support that makes carrying the device around very simple and easy.

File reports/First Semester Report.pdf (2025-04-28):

## Boston University Electrical & Computer Engineering

EC463 Senior Design Project

## First Semester Report

## Portable Language Translator

Team 23
Portable Language Translator

Team Members

Andrew Nguyen aynguyen@bu.edu
Cristian Palencia cris0211@bu.edu
Ryan Liao ryanliao@bu.edu
Yohan Kim yohank@bu.edu

Submitted: 2024-12-07

Team 23 Portable Language Translator | 12/7/2024

First Semester Report | 2

Table of Contents

Executive Summary | 2
1.0 | Introduction | 3
2.0 | Concept Development | 4
2.1 | Customer Problem | 4
2.2 | Conceptual Approach | 4
3.0 | System Description | 7
3.1 | System Architecture | 7
3.2 | System Block Diagram | 8
4.0 | First Semester Progress | 10
5.0 | Technical Plan | 12
5.1 | Hardware Advancements | 12
5.2 | Gesture Model Creation | 13
5.3 | Web Application | 14
5.4 | Encasing | 14
5.5 | Integration | 15
6.0 | Budget Estimate | 16
7.0 | Attachments | 17
7.1 | Appendix 1 – Engineering Requirements | 17
7.2 | Appendix 2 – Gantt Chart | 18
7.3 | Appendix 3 – Other Appendices | 19
7.4 | Appendix 4 – Team Information Sheet | 27

Executive Summary
Authored: Andrew Nguyen
Portable Language Translator 23 – PLT

Communication is one of humanity’s most fundamental needs, yet language barriers and lack of widespread knowledge of ASL hinder our ability to connect. Our project aims to provide an all-in-one translation device that enables real-time translation between spoken languages and seamless conversation between ASL and speech. Our device will use speech recognition and translation, a camera, and a screen, all in a portable form factor to bridge communication gaps. It will enable users to engage in natural conversations, translating spoken words bidirectionally and interpreting ASL gestures into speech, fostering inclusivity and accessibility for diverse communities.

### 1.0 Introduction

Authored: Ryan Liao
Language barriers can hinder effective communication, especially where there is a need for instant and reliable translation of spoken languages or American Sign Language (ASL). This can create challenges in accessibility, inclusivity and seamless interactions. There are many language devices that address spoken language, but very few offer solutions for translating ASL gestures which leaves a gap in supporting the Deaf and Hard of Hearing communities. Also, there is a need for a portable, efficient and easy to use solution that integrates both spoken and gesture-based translations.
One of the team’s members, Andrew, worked at a popular matcha cafe this previous summer. The lines were very long and went out the front door. Andrew needed to work very efficiently to ensure each customer received their orders in a quick manner. There were times where Spanish speakers came in and it was difficult to communicate with them. With this difficulty communicating, there was potential for wrong orders which would take more time to fix. With the Portable Language Translator, this communication would be simplified and prevent any misunderstandings.
Our project aims to solve this problem by developing a portable language translator that bridges the communication gap by enabling seamless translation of both spoken languages and ASL into spoken output. This will promote accessibility as well as inclusivity in personal and professional interactions. Our device will combine a microcontroller, video input for ASL gestures, and Google Cloud services to process spoken and gesture based inputs. We are using Google’s text-to-speech, translation and speech-text APIs and an ML model to recognize ASL letters and gestures. Preprocessed input data will be sent to the Google Cloud for translation and the results will be returned as an audio or visual output. In terms of hardware, the device will utilize a camera, microphone and an OLED display. The camera and microphone will be used to take in ASL as a visual input and spoken language as an audio input respectively. The OLED screen will be used in the ASL mode for the deaf/hard of hearing user as the spoken language will be displayed on the screen for them to read.
Our device will solve the user’s problems and needs by providing a unified solution for both spoken and ASL translations which will address the needs of people who encounter language barriers in real time. Its portability ensures convenience along with accurate translations in real time.

Special Features of our project include:
- Dual Translation Modes: Support of both spoken language translation and ASL translation
- Portable Design: Compact and lightweight device that will be able to be held in one hand for easy on-the-go use
- Cloud Integration: Leverages Google Cloud for high accuracy translations as well as hosting our future ML model
- ML Model: Trained model that uses keypoints on your hand to identify ASL letters

### 2.0 Concept Development

Authored: Andrew Nguyen

### 2.1 Customer Problem

1. Real-Time Bidirectional Translation: Desires a device that must process and translate spoken input of specified languages and provide smooth translations between those languages.
2. Language Detection: The device should be able to automatically detect what language is spoken, as to minimize user input when using it.
3. Controlled Voice Detection: The device should not detect everything spoken around it and should stay constrained to the users’ conversation and voices in the immediate vicinity.
4. ASL Translation: Desires a device that can process and translate ASL and process that into audio for the user to understand.
5. Speech-to-text: In order to communicate with someone with hearing impairments, transcription of speech and a display is necessary.
6. Portability: A translation device should be compact, lightweight, and able to be carried around in daily life without being intrusive.
7. User-Friendly Operation: A device should be easy to use with intuitive design choices as to reduce any learning curve and allow immediate use.
8. Multimodal: A device with both speech and ASL capabilities should allow the option to switch between these modes and also be able to change various settings to personalize the users’ experience.

### 2.2 Conceptual Approach

Hardware:
The proposed solution is a compact, clip-on device with the following hardware modules:
- Microcontroller: Manages core processing tasks, acting as the device’s brain for coordinating data input, processing, and output.

- Camera: Captures ASL gestures, allowing the device to interpret sign language in real-time. This inclusion addresses the gap in communication tools for the deaf and hard-of-hearing community.
- Speaker: Delivers clear, audible translations for spoken language users, enabling bidirectional conversation.
- Microphone: Detects speech input within a conversational range, enabling smooth, hands-free operation without requiring the user to hold or adjust the device.
- Screen: Displays text translations for users who prefer visual output or for those interacting with ASL users.
- Buttons: Physical buttons provide intuitive controls for power, mode switching, and other settings.
- LED Lights: Offer visual indicators for power and mode, keeping the user informed about the device's functionality at a glance.
- Bluetooth/Wi-Fi Connectivity: Enables the device to communicate with a web application and utilize cloud services for high-accuracy translation processing.
- Battery: A rechargeable battery provides portable power for 2–6 hours of continuous use, ensuring the device meets the demands of daily life.
- Encasing: The encasing is lightweight, durable, and designed with a wearable clip-on mechanism, ensuring comfort and convenience for users in various scenarios.

Software:
The software is modular, with three primary components designed to address the diverse functionality of the device:
1. Language Translation Module
- Handles speech-to-speech and speech-to-text translations using GCP.
- Utilizes automatic language detection and translation APIs to minimize user input.
- Ensures hands-free operation, allowing users to communicate naturally without interruptions.
2. ASL Translation Module
- Processes video input from the camera to detect and interpret ASL gestures using machine learning models.
- Supports the creation of words and sentences from ASL letters, enabling meaningful and fluid communication.
- Bridges the gap for the deaf and hard-of-hearing community, offering a communication tool that is often overlooked in the market.

3. Web Application Module
- Provides a user-friendly interface for customizing device settings, such as selecting languages, voices, and modes.
- Enables easy configuration and updates, ensuring the device adapts to the evolving needs of its users.
- Accessible from any internet-connected device, enhancing flexibility and user control.

This approach prioritizes inclusivity, adaptability, and ease of use, ensuring the device meets the diverse needs of users across different languages and communication modes. By integrating ASL alongside spoken languages, it addresses a critical gap in communication tools and fosters connections between signing and non-signing users. Automatic language detection and hands-free operation make the device intuitive and accessible, eliminating the need for constant interaction. The modular design of the software and hardware ensures scalability and adaptability for future updates, while its lightweight, wearable design guarantees portability and comfort for everyday use. By streamlining translation processes and offering seamless, real-time interaction, the device enables meaningful, barrier-free communication, making it a practical and impactful solution for a wide range of users.

Alternative Approaches
1. Sole Language Functionality Device: This alternative dropped the ASL functionality and focused on language translation between two parties. This would maximize portability of the device as we would not need certain hardware modules. This was dropped because of the presence of a multitude of competing technologies already on the market.
2. Portable, but non-wearable design: This alternative is in a larger form to increase the quality and speed of each of the hardware components. This could be a handheld or device that sits on a flat service. This was not pursued as it only served a part of a customer base. If we were to serve the purpose of helping travelers, having a device you need to hold would decrease the usability.

### 3.0 System Description

Authored: Yohan Kim

### 3.1 System Architecture

The Portable Language Translator system integrates three primary processing subsystems: Language Translation, ASL-to-Speech Translation, and Speech-to-Text Translation. These subsystems collectively ensure accurate and efficient real-time communication between users. Below is a detailed explanation of each subsystem.
The Language Translation subsystem processes spoken language inputs and converts them into another spoken language. The process begins by capturing audio using an I2S MEMS microphone, which is processed to detect speech using the WebRTC VAD (Voice Activity Detection) library. This ensures that only relevant speech segments are processed. Once speech is detected, it is converted to text using Google Cloud's Speech-to-Text API. The text is then translated into the desired language using Google Cloud's Translation API. Finally, the translated text is synthesized into speech via Google Cloud's Text-to-Speech API, which is played back to the user through a USB speaker. This subsystem enables seamless bidirectional speech-to-speech communication between users speaking different languages.
The ASL-to-Speech Translation subsystem focuses on translating American Sign Language gestures into spoken language. A USB 2.0 camera captures live video streams of the user's hand gestures. Using OpenCV, each video frame is processed with MediaPipe Hands to detect 21 key hand landmarks. These landmarks are normalized and fed into a pre-trained KeyPointClassifier model, which identifies the corresponding ASL letter. A stability timer ensures that only stable gestures are classified. Detected letters are concatenated to form words, which is further fixed using an integrated autocorrection system to correct spelling, grammar, and punctuation errors. Once the sentence is finalized, it is converted into speech using Google Cloud's Text-to-Speech API, allowing for direct audio output of the translated sign language.
The Speech-to-Text Translation subsystem provides transcriptions of spoken language for users relying on visual text outputs. Similar to the Language Translation subsystem, this process begins with audio input captured by the I2S MEMS microphone. The WebRTC VAD library detects speech, and the audio is processed by Google Cloud's Speech-to-Text API to generate a text transcription. The resulting text is displayed on the device's OLED screen, enabling users who rely on text-based communication to understand the spoken input.
Finally, a React-based web app allows users to set parameters, including the base language and voice preferences.

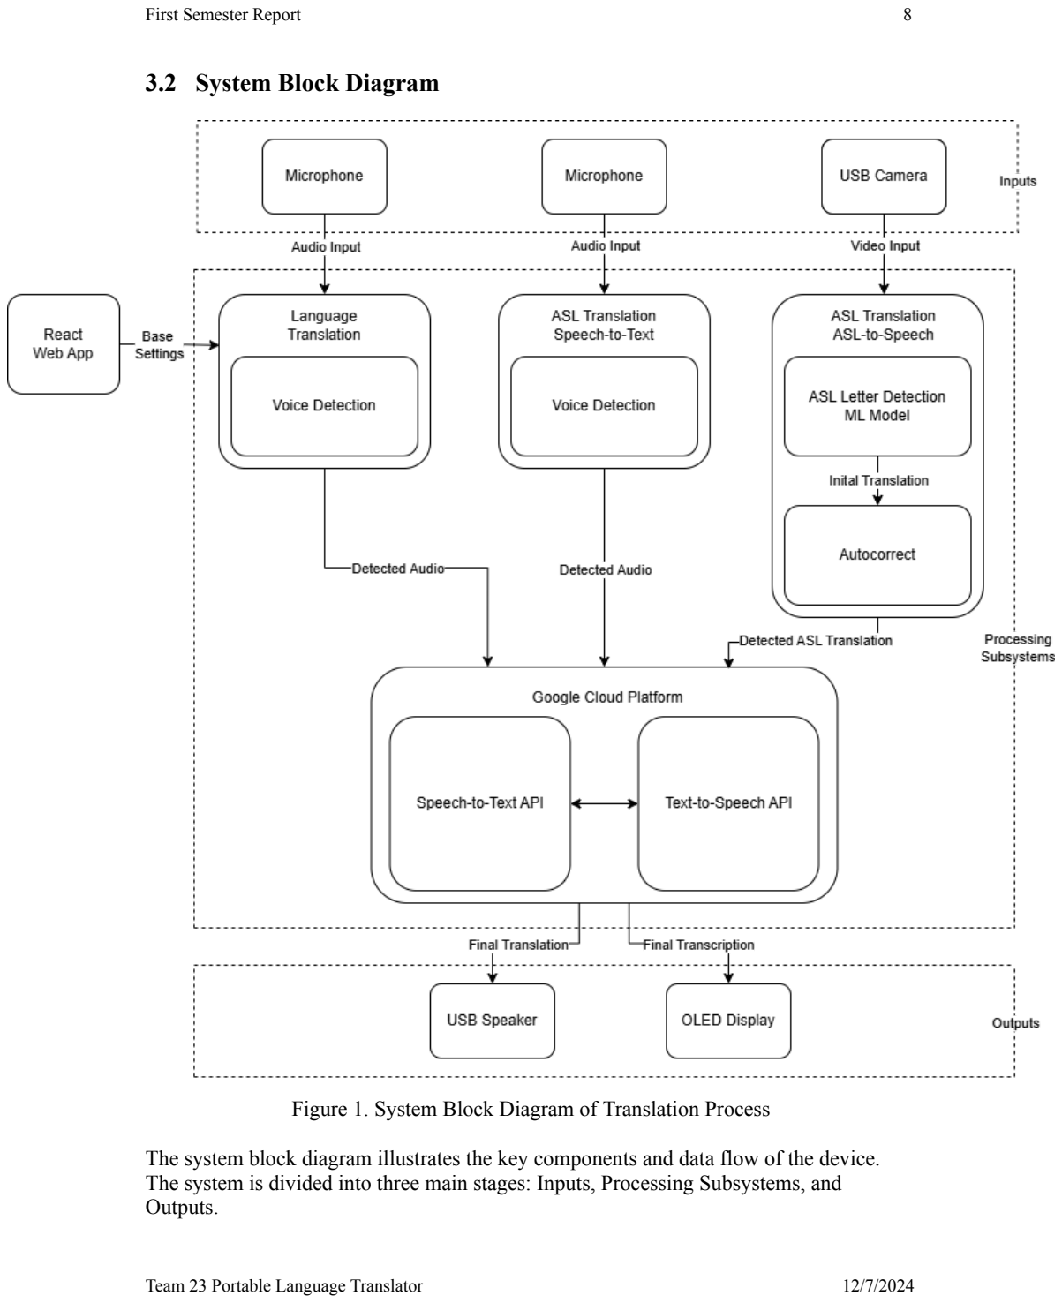
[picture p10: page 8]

### 3.2 System Block Diagram

Figure 1. System Block Diagram of Translation Process

The system block diagram illustrates the key components and data flow of the device. The system is divided into three main stages: Inputs, Processing Subsystems, and Outputs.

Inputs
Audio input is captured by a single microphone and is used for both the Language Translation subsystem for translating spoken languages and the ASL Translation (Speech-to-Text) subsystem for converting spoken language to textual output. Video input is captured by a USB camera, which sends a live feed to the ASL Translation (ASL-to-Speech) subsystem to detect and classify American Sign Language gestures.

Processing Subsystems
The Language Translation subsystem includes voice detection, which isolates relevant audio segments and processes them for translation. The ASL Translation (Speech-to-Text) subsystem similarly uses voice detection to process audio for generating text transcriptions. The ASL Translation (ASL-to-Speech) subsystem uses an ML model for ASL letter detection and initial translation. It refines results with an auto correction module to fix any spelling, grammar, and punctuation mistakes before converting the output into speech. All three processing subsystems rely on the Google Cloud Platform, leveraging its Speech-to-Text API for transcription and Text-to-Speech API for speech generation.

Outputs
Translations and transcriptions are presented through two output devices: a USB speaker for audio output and an OLED display for visual output. The speaker plays back synthesized speech for both language translation and ASL-to-speech translations, while the OLED display provides real-time feedback, such as text transcriptions.

### 4.0 First Semester Progress

Authored: Cristian Palencia, Andrew Nguyen, Yohan Kim, Ryan Liao

Language Software
The language software logic for bidirectional translation is complete. The software listens for voice activity using a voice activity detection library. When it hears voice activity and then none, it knows to send the audio chunk the Google for processing. The Google Cloud transcribes while detecting the language, translates the text, and then performs text-to-speech in the target language. The audio is then played back through the speaker. The software automatically sets the language mode based on settings from the web application and the language detected to facilitate a conversation without manual input from the user. Testing data can be found in the appendix 7.3, tables 1-7

Web Application
The web application is currently able to set the base language of the user and the voice gender of the audio playback and send that to the language software via flask API.

ASL Software
This semester, the main goal for the ASL translation was to create a working system that could translate ASL letters into English sentences. This goal was achieved with the essential functionality of processing ASL input and translating into meaningful text.
The ASL translation was done by using a live video feed from a USB camera. Then MediaPipe Hands was used to detect and process hand landmarks which were further used as input in a pre-trained key point classifier model. The model identifies the corresponding ASL letter and then adds the letter into a string of words. Once no more letters are being detected, the initial output goes through an autocorrect script that utilizes Google’s Gemini AI to fix any spelling, grammar, and punctuation mistakes.
Testing results for the ASL translation, outlined in appendix 3, 7.3, tables 8-9 shows the current translation capabilities. The raw output from the recognition model sometimes had errors such as incorrect letters, spacing problems, or substitutions. These errors were more common when the user was positioned 1 meter away from the camera, indicating that distance impacts recognition accuracy. Nevertheless, the integrated autocorrection system effectively resolved most of these issues, significantly improving the quality of the final output. Even at the maximum tested distance, the system reliably produced accurate sentences. The average time taken to process and correct a sentence was recorded at 3.57 seconds. This performance remained stable across various phrases, showing little variation irrespective of sentence length.

Hardware and Firmware
This semester's focus with hardware was to focus on finding and developing the core components of the project: microphone, display, camera, speaker, and microcontroller. Currently we have all of our hardware working off a Raspberry Pi 3 but ready to be moved to our Jetson Nano. We were able to successfully implement firmware files to create classes for the OLED display, microphone, and speaker. With these classes implemented we are able to have full and complete control over each hardware component. This functionality provides a great basis for continuing and testing development next semester from the Jetson Nano. One of our main requirements from a hardware standpoint was the functional distance of the microphone. Relevant data about the functional distance of the microphone can be found in Appendix 3 in Tables 10 and
11. These tables demonstrate that we met the requirement that language can be understood from a 1m range with our current microphone.

### 5.0 Technical Plan

Authored: Cristian Palencia

For the upcoming semester we have the following main developments and considerations in mind: hardware advancements, gesture model creation, Web App improvements, encasing, and integration.

5.1 Hardware Advancements
Next semester we want to ensure that we are able to implement and use a battery, allow our device to have some method of connectivity whether it be via bluetooth or internet, and finally ensure that we finalize all microcontroller decisions early on in the semester.

Battery
For our design we want to find a small battery with reasonable power capabilities. Additionally, we want to ensure that our battery can be recharged such that our device can continue being used even when the battery has been completely depleted. Thus, we will research appropriate batteries and implement the additional hardware required to make it rechargeable.
In order to implement this, we understand that it’s not as simple as ordering a rechargeable battery, thus we will make sure to research the relevant hardware needed to ensure rechargeability. Furthermore, we have a requirement of a battery life of 2-8 hours per full charge depending on the current functional mode of the device. To ensure this requirement is met, we will evaluate the power consumption of our finalized parts at the beginning of the semester in order to ensure that we can find a battery that fulfills this requirement.
Finally, we will make sure that we research batteries with size and weight as a heavily weighed factor to ensure that our device remains portable.
With these considerations in mind, we hope to find our battery early on into the semester since finding a good battery is also dependent on having all our hardware finalized.
Since this is a hardware component Cristian Palencia will be in charge of handling this in the first weeks of the semester.

Device Connectivity
Our design is expected to be a fully stand alone, portable device that has no external wire connections. Thus we plan to implement a connectivity module into our microcontroller.

We plan on either implementing internet or bluetooth connectivity. Internet connectivity would allow the device to be fully independent while bluetooth would require dependence on a phone to connect to. We will evaluate the positives and negatives for both design choices. Additionally, we will find an appropriate USB module as it will be a simple integration since it will not need to integrate with GPIO pins. Since this is a hardware component Cristian Palencia will be in charge of handling this in the first weeks of the semester.

Finalize Microcontroller
We moved over to a Jetson Nano at the end of the semester due to its computational strength. Very early on in the semester we plan on fully making the transition to the Jetson Nano in order to optimize our design speeds. In order to do this we will face the following challenges: outdated OS and size.
From initial attempts with the OS we found that its quite outdated (Ubuntu 18) and caused some library conflicts. We will determine a workaround for the outdated OS to allow our software to be able to run on the Jetson Nano.
Despite the computational strength of the Jetson Nano it contradicts our portability requirement for the device. Thus, we will work closely with Professor Osama in order to make plans to reduce the size of the Jetson Nano and include only hardware components that are strictly required for functionality of our product.
Since this is a hardware component Cristian Palencia will be in charge of handling this in the first weeks of the semester but will work closely with Yohan Kim and Andrew Nguyen to ensure library compatibility is properly met.

5.2 Gesture Model Creation
We will develop a gesture model that reads in gestures and translates them to English. We want to focus on implementing this with 5-10 gestures. For all Gesture Model related tasks it will be a collective effort between Andrew Nguyen, Ryan Liao, and Yohan Kim since we understand this is one of the most difficult tasks of the project.

Research
We want to allocate the beginning of the semester to researching the best way to take video input as data and the best way to structure our model to handle that data.

Collect Training Data
We will then start collecting video data of different gestures with our USB camera. This will include extensive recordings of the gestures repeated in a variety of settings if a premade dataset is not readily available.

Develop and Train Model
Once we have all of our training data we will begin to train a model on gesture recognition for use in our ASL detection software using a neural network with tools from Tensorflow.js. The video will be compressed into an image that represents the entire gesture and be trained off of that.

5.3 Web Application
We want to make minor yet relevant improvements to our web application such that it adds more functionality but also is more user friendly.

GCP collection
We will add the full google cloud platform catalog of voices such that users are able to have full choice over the voice they would like to hear output from the device. Andrew Nguyen developed the prototype version of the Web Application and so will be in charge of all modifications to it. He will work on it in the first week of the semester such that he can then move his focus towards aiding in the development of the Gesture Model along with Yohan Kim and Ryan Liao.

Update UI
We will make the UI more visually pleasing and user friendly. This will be done by modifying relevant HTML and CSS files.
As previously mentioned, Andrew Nguyen developed the prototype version of the Web Application and so will be in charge of all modifications to it. He will work on it in the first week of the semester such that he can then move his focus towards aiding in the development of the Gesture Model along with Yohan Kim and Ryan Liao.

5.4 Encasing
We will design an encasing that permits the user to clip the device comfortably and easily with all parts mounted appropriately.

Collect Measurements
We will collect relevant measurements of the different hardware components of the project before beginning 3D modelling. This will serve as a good starting point to begin designing.
Yohan Kim and Cristian Palencia will work on this together once all the hardware has been ordered and delivered.

3D Model and Print
Once measurements have been completed we will begin to consider the physical design architecture. This will be done first in drafts and then it will be moved over to a 3D modeling software of our preference like Fusion 360 or Onshape.
Yohan Kim will be primarily in charge of the design with the assistance of Cristian Palencia to ensure proper communication about hardware components and their physical mounting.

Mount Components
Once we have finished a preliminary 3D print we will start mounting all hardware components to ensure that everything fits as we need. We will make design revisions and return to modelling as we deem necessary. Revision consideration will depend on portability behavior. Thus, we shall test if the design allows the user to clip on the device easily and comfortability with all relevant hardware in place.
Yohan Kim and Cristian Palencia will work closely with this to ensure hardware integrity and functionality is kept during mounting.

5.5 Integration

Software Integration onto Microcontroller
Once we have finalized all software and the microcontroller we will fully integrate the two. This is to ensure that the microcontroller can properly run all our code off of the microcontroller OS and we can make modifications as needed. This is with the primary focus on the gesture model and the expectation is that other relevant completed software components will have already been tested on the microcontroller earlier in the semester.
This will be led primarily by Cristian Palencia and he will communicate with other members of the team to understand library dependencies and requirements. We will dedicate a large portion of March to ensure that this is done thoroughly and with time to fix any issues that may arise.

Software and Hardware Integration
With code fully running on the microcontroller, we will then ensure that the software is able to fully interface with the hardware in a coherent manner that is reflective of the full device behavior.
This will be a team effort to ensure full system integration. We will dedicate a large portion of March to ensure that this is done thoroughly and with time to fix any issues that may arise.

### 6.0 Budget Estimate

Authored: Cristian Palencia

Item | Description | Cost
1 | Adafruit Microphone | $7
2 | Jetson Nano | $215
3 | USB Speaker | $15
4 | USB Camera | $12
5 | OLED Display | $13
6 | Wireless Module | $10
7 | Battery | $40
8 | Bluetooth Module | $10
| Total Cost | $322

The following includes all relevant parts we envision ourselves using for a final design. We currently include the prices for both the Wireless and Bluetooth module since we aren’t completely sure which we will go with yet. Another relevant note is on the price of the Jetson Nano. It is our most expensive part as it helps significantly with performing operations locally rather than through the cloud. Additionally, we may consider implementing a more recent Jetson Nano, the Jetson Nano Oran which instead costs $500. In this case our final budget cost would be $607 instead of $322. This could be a relevant consideration just to ensure maximum performance with the most recent OS version to support all our needed libraries.

### 7.0 Attachments

### 7.1 Appendix 1 – Engineering Requirements

Authored: Ryan Liao

Team #23 Team Name: PLT

Project Name: Portable Language Translator

Requirement | Value, Range, Tolerance, Units
Case Dimensions | 140mm x 100mm x 80mm
Power | 5V battery
Battery Life (Speech) | < 3 sec
Battery Life (ASL) | < 4 sec
Speech Detection Range | 50 - 70 dB within 1 m
ASL Detection Range | 1 m
Weight | < 200 g

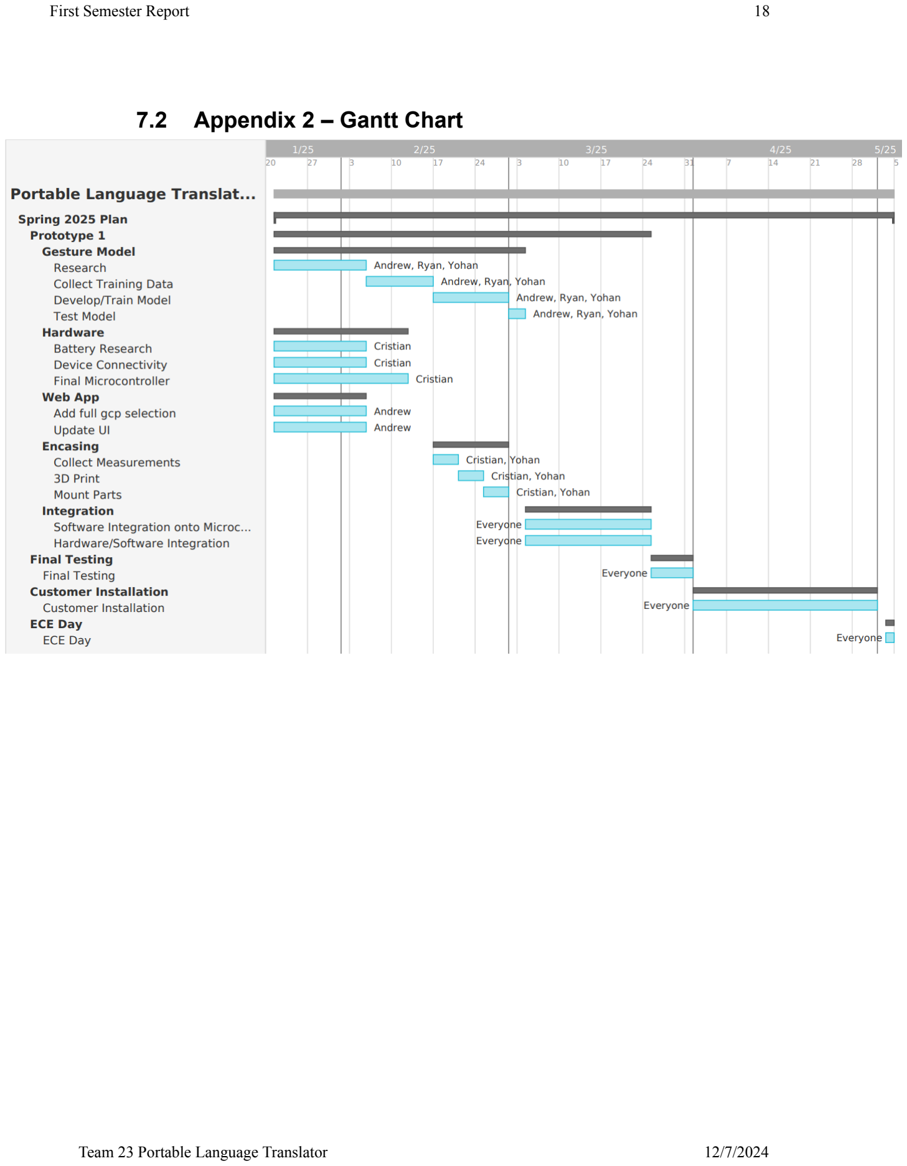
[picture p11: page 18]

### 7.2 Appendix 2 – Gantt Chart

You need not include other MS Project columns like start and end dates, durations, support, etc. Make major milestones clear

### 7.3 Appendix 3 – Other Appendices

Language Accuracy Tests:
Phrase Said | Phrase Recorded | Translated Phrase | Errors
Hello, how are you? | hello how are you | 안녕하세요. 어떻게 지내세요 | Transcription: no errors Translation: no errors
Can I get a large coffee with two sugars and no milk, please? | can I get a large coffee with Two Sugars and no milk | Two Sugars와 우유 없이 큰 커피 한 잔을 마실 수 있나요? | Transcription: no errors Translation: no errors
Excuse me, how do I get to the nearest train station? | excuse me how do I get to the nearest train station | 실례합니다. 가장 가까운 기차역까지 어떻게 가나요? | Transcription: no errors Translation: no errors

Table 1: English - Korean Translation

Phrase Said | Phrase Recorded | Translated Phrase | Errors
Do you have fresh strawberries or are they out of season? | you have fresh strawberries or are they out of season | ¿Tienes fresas frescas o están fuera de temporada? | Transcription: missing word Translation: no errors
Can I try this jacket on in a medium size? | can I try this jacket on in a medium sized | ¿Puedo probarme esta chaqueta en talla mediana? | Transcription: minor error Translation: no errors
What time are we meeting tomorrow for lunch at the new restaurant? | what time are we meeting tomorrow for lunch at the new | ¿A qué hora nos reuniremos mañana para almorzar en el nuevo? | Transcription: missing word Translation: no errors

Table 2: English - Spanish Translation

Phrase Said | Phrase Recorded | Translated Phrase | Errors
¿Hola, tienes fresas frescas o están fuera de temporada? | Hola tienes fresas frescas o están fuera de temporada | 안녕하세요. 신선한 딸기가 있나요? 아니면 제철이 아니나요? | Transcription: no errors Translation: no errors
¿Puedo probarme esta chaqueta en talla mediana? | puedo probarme esta chaqueta en talla mediana | 이 재킷을 미디엄 사이즈로 입어봐도 될까요? | Transcription: no errors Translation: no errors
¿A qué hora nos reuniremos mañana para almorzar en el nuevo restaurante? | a qué hora nos reunimos mañana para almorzar en el nuevo restaurante | 우리 내일 몇 시에 새 식당에서 점심 먹으러 만나요? | Transcription: no errors Translation: no errors

Table 3: Spanish - Korean Translation

Phrase Said | Phrase Recorded | Translated Phrase | Errors
안녕하세요. 어떻게 지내세요 | 안녕하세요 어떻게 지내세요 | Hola, cómo estás | Transcription: no errors Translation: no errors
우유 없이 설탕 그게 큰 커피 주세요 | 우유 없이 설탕 그게 큰 커피 주세요 | Me gustaría un café grande con dos azúcares y sin leche. | Transcription: no errors Translation: no errors
실례합니다. 가장 가까운 기차역까지 어떻게 가나요? | 실례합니다 가장 가까운 기차역까지 어떻게 가나요 | Disculpe, ¿cómo llego a la estación de tren más cercana? | Transcription: no errors Translation: no errors

Table 4: Korean - Spanish Translation

Phrase Said | Phrase Recorded | Translated Phrase | Errors
신천한 딸기 있나요 아니면 제철이 아니나요 | 신천한 딸기 있나요 아니면 제철이 아니나요 | Are there any fresh strawberries or are they out of season? | Transcription: no errors Translation: no errors
이 재킷을 M 사이즈로 입어봐도 될까요 | 이 재킷을 M 사이즈로 입어봐도 될까요 | Can I try that jacket in size M? | Transcription: no errors Translation: no errors
우리 내일 몇 시에 새 식당에서 점심 먹으러 만날 거야 | 우리 내일 몇 시에 새 식당에서 점심 먹으러 만날 거야 | What time are we meeting for lunch at the new restaurant tomorrow | Transcription: no errors Translation: no errors

Table 5: Korean - English Translation

Phrase Said | Phrase Recorded | Translated Phrase | Errors
Hola, cómo estás | Hola cómo estás | Hello how are you | Transcription: no errors Translation: no errors
¿Puedo tener un café grande con dos azúcares y sin leche por favor? | puedo tener un café grande con dos azúcares y sin leche por favor | can I have a large coffee with two sugars and no milk please? | Transcription: no errors Translation: no errors
Disculpe, come alcanzo llegar al estacion de tren mas cercano? | Disculpe cómo alcanzo a llegar a la estación de tren más cercano | excuse me, how do I get to the nearest train station? | Transcription: minor errors Translation: no errors

Table 6: Spanish - English Translation

Language Latency Tests:
Phrase | Word count | Latency (seconds)
Hello | 1 | 0.36
Hello, how are you? | 4 | 0.63
I would like to have a water please | 8 | 0.67
Where is the nearest hospital? I am having a serious allergic reaction | 12 | 0.87
I always enjoy quiet evenings at home, reading a good book with a cup of tea | 16 | 1.21
Let’s plan a weekend getaway soon. It’s been too long since we all had some fun together outside at the beach | 21 | 1.22
When we moved into the new neighborhood, we didn’t know anyone, but our neighbors were so welcoming. They even brought over cookies and invited us to their backyard barbecue. It’s been a great place to live ever since | 38 | 1.92

Table 7: Latency Measurements - Data collected for latency for different sized phrases

Phrase | Distance from Camera | Before Autocorrect | After Autocorrect | Errors?
Where is that? | .33 meters | Where is that | Where is that? | No
Where is that? | .67 meters | Where is that | Where is that? | No
Where is that? | 1 meter | Whexe i ss thaa t | Where is that? | No
The car is red. | .33 meters | The car is re d | The car is red. | No
The car is red. | .67 meters | The car is r e d | The car is red. | No
The car is red. | 1 meter | The cab is r e d | The cab is red. | Yes, B was recorded instead of R
That sounds so exciting! | .33 meters | That sounds so exciting | That sounds so exciting! | No
That sounds so exciting! | .67 meters | That sounds sso exciting | That sounds so exciting! | No
That sounds so exciting! | 1 meter | That soumdss so exciting | That sounds so exciting. | Yes, it did not add the exclamation mark
Hi my name is Yohan. | .33 meters | Hi my name is yohan | Hi, my name is Yohan. | No
Hi my name is Yohan. | .67 meters | Hi my name iss yohan | Hi, my name is Yohan. | No
Hi my name is Yohan. | 1 meter | Hi my mame is yoham | Hi, my name is Yohan. | No
I went to school today and learned how to read | .33 meters | I w e n t to school and lea r ned how to read | I went to school and learned how to read. | No
I went to school today and learned how to read | .67 meters | I we n t to scool a nd lear n ed how o read | I went to school and learned how to read. | No
I went to school today and learned how to read | 1 meter | I we nt sto sc hool and learn e d how to read | I went to school and learned how to read. | No

Table 8: ASL Testing Results

Phrase | Latency (seconds)
Where is that? | 3.62
The car is red. | 3.5
Hi my name is Yohan. | 3.92
That sounds so exciting! | 3.55
I went to school today and learned how to read | 3.75

Table 9: ASL Latency Results

Quality Score | Meaning
0 | Inaudible
1 | Muffled and distant
2 | Language can be understood
3 | Clear audio
4 | Perfect audio recording

Table 10: Audio Recording Quality Table

Distance (m) | Whisper | Conversational Speaking | Yelling / Loud Speaking
0.25 | 3 | 3 | 4
0.50 | 3 | 3 | 3
0.75 | 2 | 3 | 3
1 | 2 | 2 | 3
1.25 | 2 | 2 | 3
1.50 | 1 | 1 | 3
1.75 | 1 | 1 | 3
2 | 1 | 1 | 3
Table 11: Functional Microphone Distance Table

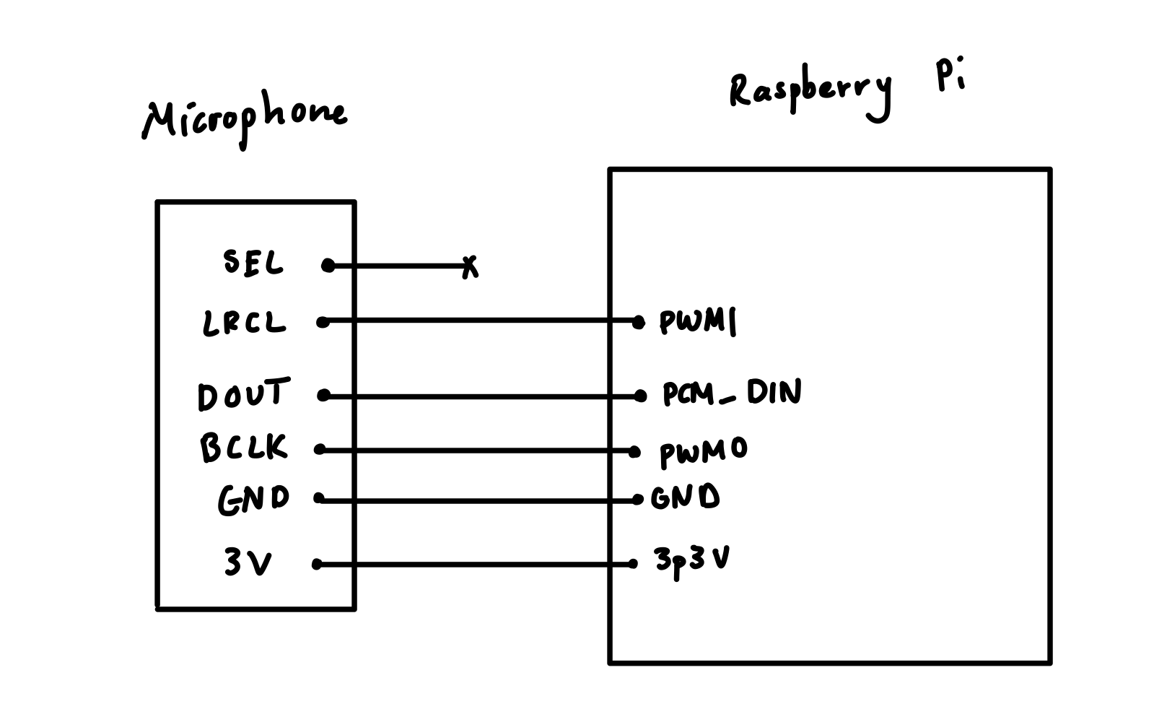
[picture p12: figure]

Figure 2: Microphone Wiring Diagram

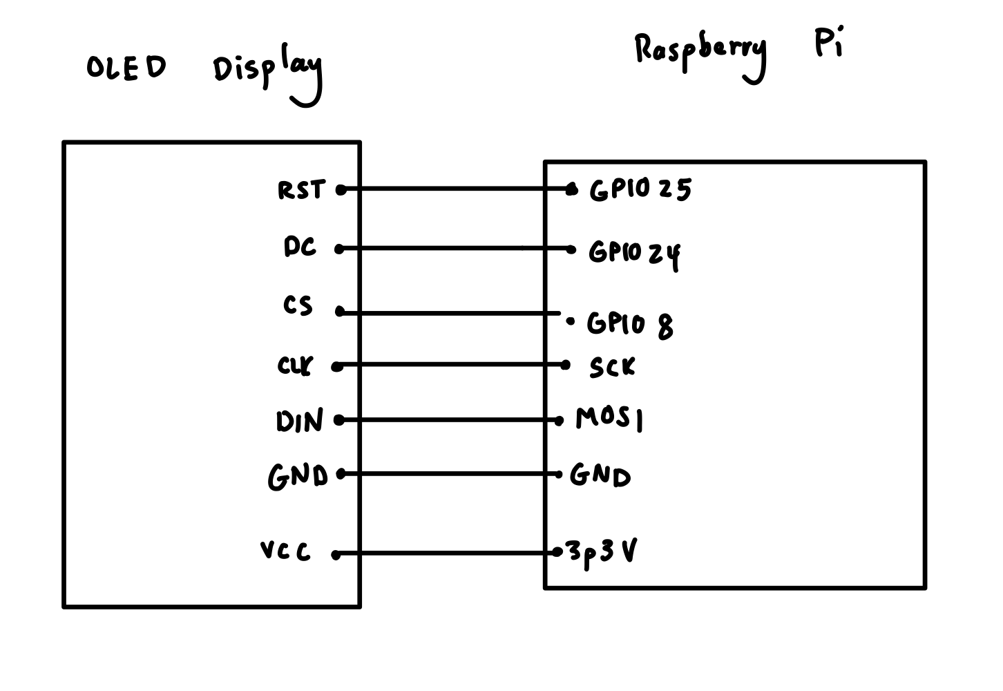
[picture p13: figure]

Figure 3: OLED Display Wiring Diagram

### 7.4 Team Information Sheet

Biographical Information
Cristian Palencia
I am a Computer Engineering major from Framingham, Massachusetts. From a relatively young age I’ve always enjoyed working with computers and computer parts. For that reason I decided to go into Computer Engineering in college and pursue a career that allows me to dive deeper into those interests. Specifically, throughout my time in Boston University I have discovered a main interest in Embedded Systems. For this reason I have posed myself as such for our project. I enjoy working with hardware components and being able to write code to actualize them.

Contact Information
- email: cris0211@bu.edu
- phone: 508-630-6468

Andrew Nguyen
I am a Computer Engineering major with an emphasis on full-stack development, machine learning, and computer graphics. I am passionate about technology as a whole but I am really interested in games and VR.

Contact Information:
- email: aynguyen@bu.edu

Yohan Kim
I am a senior majoring in Computer Engineering. Throughout my college career I have been interested in software engineering with an emphasis on backend engineering. I am passionate about creating impactful solutions and continuously expanding and learning new skills in the area of software engineering.

Contact Information
- email: yohank@bu.edu
- phone: 408-809-6250

Ryan Liao
I am a senior Computer Engineering student pursuing a concentration in Machine Learning from Beacon, NY. I want to use my experiences from college to create solutions that drive positive societal impact.
Contact Information
- email: ryanliao@bu.edu
- phone: 845-542-8689

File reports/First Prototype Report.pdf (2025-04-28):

# Boston University Electrical & Computer Engineering

EC 463 Senior Design Project

## First Prototype Report

Portable Language Translator


By

Team 23

Portable Language Translator

Team Members

Yohan Kim yohank@bu.edu
Ryan Liao ryanliao@bu.edu
Cristian Palencia cris0211@bu.edu Andrew Nguyen aynguyen@bu.edu

Equipment and Setup:

For the language translation on computer, a react web app is used to control the base language and voice settings of the program, which it sends using a flask api. One device is used for the conversation. The users must wait for the translation and playback to fully finish before beginning the next phrase. The program captures audio, splits it into chunks and uses voice activity detection software to determine if someone is speaking. Once it detects no speech, it sends the audio file to the google cloud for the transcription, translation, and finally text-to-speech. The audio file is sent back to the program which it plays from the system’s speaker.
For the ASL detection on computer, the external camera (USB 2.0 Camera) will record a live video stream and the script will initialize the video feed. Mediapipe Hands will detect the hand in the video feed and locate 21 key landmarks along the user’s hand which are then normalized and prepared for classification. The keypoints are passed into the KeyPointClassifier, which is a pre-trained ML model that matches the keypoints to an ASL alphabet gesture. Each frame is checked to identify the letter being signed and the predicted letter is displayed on the laptop screen. If the signed label is held stable for .75 seconds then the detected letter will be put into the detected string. The user will consecutively sign letters until their word is complete. Once 2 seconds have passed, the detected string will be updated into the word list and the user may continue signing their next word if needed. Once the user has stopped signing their sentence for 3 seconds, the finalized word list/sentence is moved into a txt file.
For the hardware setup we have a Raspberry Pi 3 that interfaces with all the relevant components. For one, we use the GPIO pins to connect to the SPI interface for the OLED display. The OLED display interfaces with the adafruit_ssd1309 library to send over the appropriate signals over the GPIOs and uses PIL to allow for relevant drawing capabilities to the OLED. Additionally, we have our I2S MEMS microphone also connected to the Pi’s GPIO pins. The microphone directly interfaces with the sounddevice library which handles reading from a connected I2S audio device such that we can generate a .wav file recording. Finally, we have a USB 2.0 Speaker that, using the pygame library, can output the audio recorded by the microphone, or any provided .wav file.

Measurements and Data:

Measurements and Data:

Language tests
Accuracy: We wanted to collect some data to demonstrate the accuracy and functionality of our language translation code. The data collected in Tables 1-6 below demonstrates different translation paths such as English - Korean and Korean - Spanish. For each row we notice: “Phrase Said” being the words spoken by the user, “Phrase Recorded” being the words picked up by the software, “Translated Phrase” being the final translation that is determined and outputted by the software. Under “Errors?” we write the degree to which the translation and transcription were incorrect. Transcriptions defines whether the actual translation was wrong while the Translation then describes whether given a transcription we were able to correctly output it.
Phrase Said | Phrase Recorded | Translated Phrase | Errors
Hello, how are you? | hello how are you | 안녕하세요. 어떻게 지내세요 | Transcription: no errors Translation: no errors
Can I get a large coffee with two sugars and no milk, please? | can I get a large coffee with Two Sugars and no milk | Two Sugars와 우유 없이 큰 커피 한 잔을 마실 수 있나요? | Transcription: no errors Translation: no errors
Excuse me, how do I get to the nearest train station? | excuse me how do I get to the nearest train station | 실례합니다. 가장 가까운 기차역까지 어떻게 가나요? | Transcription: no errors Translation: no errors

Table 1: English - Korean Translation

Phrase Said | Phrase Recorded | Translated Phrase | Errors
Do you have fresh strawberries or are they out of season? | you have fresh strawberries or are they out of season | ¿Tienes fresas frescas o están fuera de temporada? | Transcription: missing word Translation: no errors
Can I try this jacket on in a medium size? | can I try this jacket on in a medium sized | ¿Puedo probarme esta chaqueta en talla mediana? | Transcription: minor error Translation: no errors
What time are we meeting tomorrow for lunch at the new | what time are we meeting tomorrow for lunch at the new | ¿A qué hora nos reuniremos mañana para almorzar en el | Transcription: missing word Translation: no errors

restaurant? | nuevo?
Table 2: English - Spanish Translation
Phrase Said | Phrase Recorded | Translated Phrase | Errors
¿Hola, tienes fresas frescas o están fuera de temporada? | Hola tienes fresas frescas o están fuera de temporada | 안녕하세요. 신선한 딸기가 있나요? 아니면 제철이 아니나요? | Transcription: no errors Translation: no errors
¿Puedo probarme esta chaqueta en talla mediana? | puedo probarme esta chaqueta en talla mediana | 이 재킷을 미디엄 사이즈로 입어봐도 될까요? | Transcription: no errors Translation: no errors
¿A qué hora nos reuniremos mañana para almorzar en el nuevo restaurante? | a qué hora nos reunimos mañana para almorzar en el nuevo restaurante | 우리 내일 몇 시에 새 식당에서 점심 먹으러 만나요? | Transcription: no errors Translation: no errors

Table 3: Spanish - Korean Translation

Phrase Said | Phrase Recorded | Translated Phrase | Errors
안녕하세요. 어떻게 지내세요 | 안녕하세요 어떻게 지내세요 | Hola, cómo estás | Transcription: no errors Translation: no errors
우유 없이 설탕 그게 큰 커피 주세요 | 우유 없이 설탕 그게 큰 커피 주세요 | Me gustaría un café grande con dos azúcares y sin leche. | Transcription: no errors Translation: no errors
실례합니다. 가장 가까운 기차역까지 어떻게 가나요? | 실례합니다 가장 가까운 기차역까지 어떻게 가나요 | Disculpe, ¿cómo llego a la estación de tren más cercana? | Transcription: no errors Translation: no errors

Table 4: Korean - Spanish Translation

Phrase Said | Phrase Recorded | Translated Phrase | Errors
신천한 딸기 있나요 아니면 제철이 아니나요 | 신천한 딸기 있나요 아니면 제철이 아니나요 | Are there any fresh strawberries or are they out of season? | Transcription: no errors Translation: no errors

이 재킷을 M 사이즈로 입어봐도 될까요 | 이 재킷을 M 사이즈로 입어봐도 될까요 | Can I try that jacket in size M? | Transcription: no errors Translation: no errors
우리 내일 몇 시에 새 식당에서 점심 먹으러 만날 거야 | 우리 내일 몇 시에 새 식당에서 점심 먹으러 만날 거야 | What time are we meeting for lunch at the new restaurant tomorrow | Transcription: no errors Translation: no errors

Table 5: Korean - English Translation

Phrase Said | Phrase Recorded | Translated Phrase | Errors
Hola, cómo estás | Hola cómo estás | Hello how are you | Transcription: no errors Translation: no errors
¿Puedo tener un café grande con dos azúcares y sin leche por favor? | puedo tener un café grande con dos azúcares y sin leche por favor | can I have a large coffee with two sugars and no milk please? | Transcription: no errors Translation: no errors
Disculpe, come alcanzo llegar al estacion de tren mas cercano? | Disculpe cómo alcanzo a llegar a la estación de tren más cercano | excuse me, how do I get to the nearest train station? | Transcription: minor errors Translation: no errors

Table 6: Spanish - English Translation

Latency: Referring to Table 7 below, we were able to record some measurements for the latency of our software for different sized phrases. For context, the data was collected using English -Spanish translations (English phrase translated into Spanish). In our collected data, latency is measured by the time the untranslated audio is sent to the cloud to when the translated audio playback starts. This was measured by the python timer method to provide accurate times.

Specifically, as we move down the table we observe that we are testing with larger and larger phrases to test the correlation between different sized phrases and latency.

ASL Test

Accuracy: With our ASL software we wanted to test that if a user were to attempt to enter in a phrase, that both the initial ASL letter detection and autocorrect model would work appropriately to read input and correct it after the fact if needed. Table 8 below demonstrates an attempted phrase at different distances as input and demonstrates the output of the ASL model and then the output of the Autocorrection model.

Phrase | Distance from Camera | Before Autocorrect | After Autocorrect | Errors?
Where is that? | .33 meters | Where is that | Where is that? | No
Where is that? | .67 meters | Where is that | Where is that? | No
Where is that? | 1 meter | Whexe i ss thaa t | Where is that? | No
The car is red. | .33 meters | The car is re d | The car is red. | No
The car is red. | .67 meters | The car is r e d | The car is red. | No
The car is red. | 1 meter | The cab is r e d | The cab is red. | Yes, B was recorded instead of R
That sounds so exciting! | .33 meters | That sounds so exciting | That sounds so exciting! | No
That sounds so exciting! | .67 meters | That sounds sso exciting | That sounds so exciting! | No
That sounds so exciting! | 1 meter | That soumdss so exciting | That sounds so exciting. | Yes, it did not add the exclamation mark
Hi my name is Yohan. | .33 meters | Hi my name is yohan | Hi, my name is Yohan. | No
Hi my name is Yohan. | .67 meters | Hi my name iss yohan | Hi, my name is Yohan. | No
Hi my name is Yohan. | 1 meter | Hi my mame is yoham | Hi, my name is Yohan. | No
I went to school today and learned | .33 meters | I w e n t to school and lea r | I went to school and learned how | No

how to read | | ned how to read | to read.
I went to school today and learned how to read | .67 meters | I we n t to scool a nd lear n ed how o read | I went to school and learned how to read. | No
I went to school today and learned how to read | 1 meter | I we nt sto sc hool and learn e d how to read | I went to school and learned how to read. | No

Table 8: ASL Translation Data - Table demonstrates how an intended phrase is translated at different distances using our ASL and Autocorrection models.

Latency: We also wanted to record measurements for the latency or processing time for the Autocorrect model took to take a recorded phrase and correct it. For a given phrase, we recorded the time it took to determine if it required correction and to actually correct it. Latency is measured by the time the last letter is detected to when the final translated sentence is returned. The program uses the python timer method to provide accurate times. Table 9 demonstrates the different phrases and then the corresponding latency in seconds.

Phrase | Latency (seconds)
Where is that? | 3.62
The car is red. | 3.5
Hi my name is Yohan. | 3.92
That sounds so exciting! | 3.55
I went to school today and learned how to read | 3.75

Table 9: ASL Latency Measurements - Demonstrates how long it took to run a given phrase through the autocorrection model (a given phrase could be mispelled as well, the latency timing is unaffected by small grammar or spelling errors)

Microphone Test

Functional Distance: In order to test the functional distance of the microphone, we first had to determine a method to rank a given audio recording. Referencing Table 10, we were able to come up with a scoring guideline for any given audio recording. With this scoring guideline we were then able to test the microphone at different distances and at varying audio levels of the phrase: “This is a test recording of the microphone”. Based on the audio recording we would then be able to give it a quality score between 0 and 4 (shown in Table 11).

Quality Score | Meaning
0 | Inaudible
1 | Muffled and distant
2 | Language can be understood
3 | Clear audio
4 | Perfect audio recording
Table 10: Quality Score Table - Ranking given to a audio recording based on overall quality.
Distance (m) | Whisper | Conversational Speaking | Yelling / Loud Speaking
0.25 | 3 | 3 | 4
0.50 | 3 | 3 | 3
0.75 | 2 | 3 | 3
1 | 2 | 2 | 3
1.25 | 2 | 2 | 3
1.50 | 1 | 1 | 3
1.75 | 1 | 1 | 3
2 | 1 | 1 | 3
Table 11: Microphone Performance - Performance of I2S microphone at varying distances and audio levels.

Conclusions:

Language
The accuracy of the transcription and translation is very accurate with only minor errors. Even with these errors, any ASL individual reading the transcribed text or other party speaking a different language should be able to understand the meaning of each phrase. This accuracy is also above our minimum expected percentage accuracy. The translation latency, understandably, increases based on the size of the phrase it has to translate. The latency of the software will also increase with more languages added to its functionality, but we have specified English, Korean, and Spanish in our project description, so the latency will not change from this. Based on our data, even with a long phrase that is unlikely to be used during a conversation as it involves multiple sentences, the latency is significantly under our benchmark of 5 seconds. With most common phrases having a latency of under 1 second, our language software should be able to seamlessly translate bidirectionally without interrupting the flow of a conversation.

ASL
The raw output from the ASL recognition model shows occasional errors in spelling, spacing, and letter substitutions, particularly when the distance from the camera increases to 1 meter. This indicates a slight decrease in the model's accuracy as the distance grows. Despite these errors, the autocorrection effectively resolves the majority of issues, including spelling, punctuation, and spacing errors. Even at the furthest distance, the autocorrection successfully fixes most recognition mistakes, significantly improving the overall quality of the output. Regarding latency, the system takes an average of 3.57 seconds to process and correct a sentence. This processing time remains relatively consistent across different phrases, with minimal variation regardless of the phrase's length or complexity.

Microphone
One of our requirements of the project is defined by how far someone can be from the device for full translation functionality. The requirement we defined was a distance of one meter away from the device. From the collected data, we notice that at even a whisper we are able to understand language spoken to the microphone at a distance of one meter away. Additionally, we observe that, as expected, below the one meter requirement that the microphone performance is increased and is decreased at distances away from the one meter requirement. Although, we are able to obtain good audio that can be translated by the software, it would be helpful to guarantee even greater audio quality from the microphone since there is the room for improvement. For this reason, our group will most likely pursue improvements to the microphone whether it be implementing audio amplifiers or filters to the system.

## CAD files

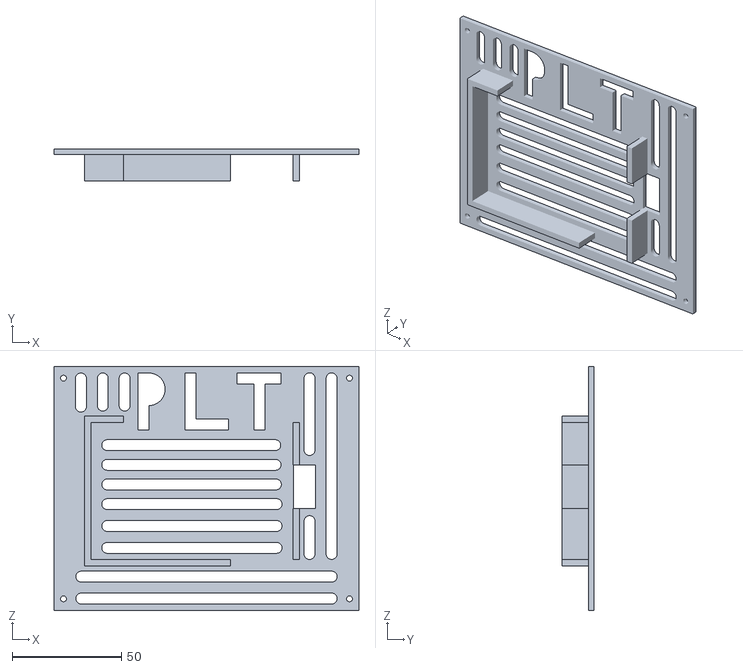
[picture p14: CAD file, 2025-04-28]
hw/cad_files/Back_Plate.stl
139.6 x 14.5 x 111.7

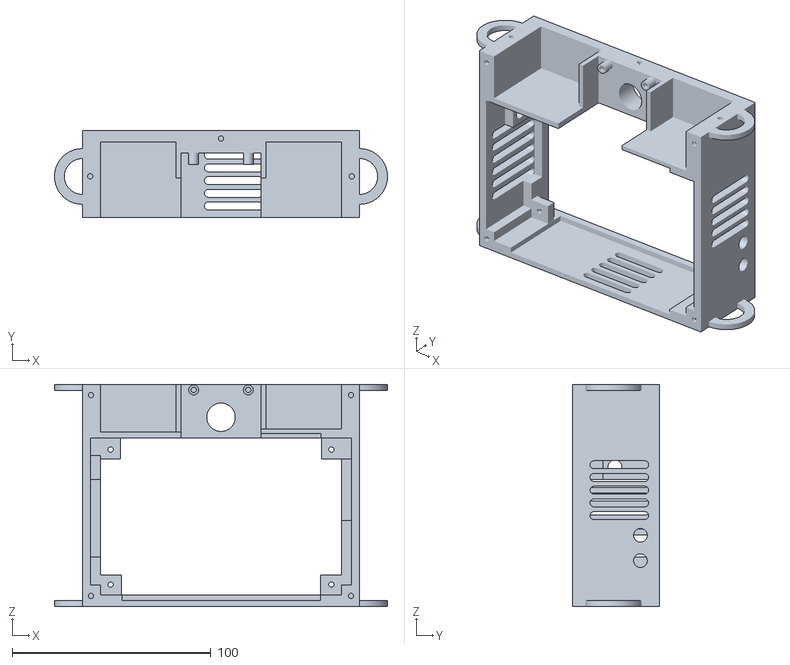
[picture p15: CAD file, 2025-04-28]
hw/cad_files/Display_Mount.stl
167.6 x 43.8 x 111.7

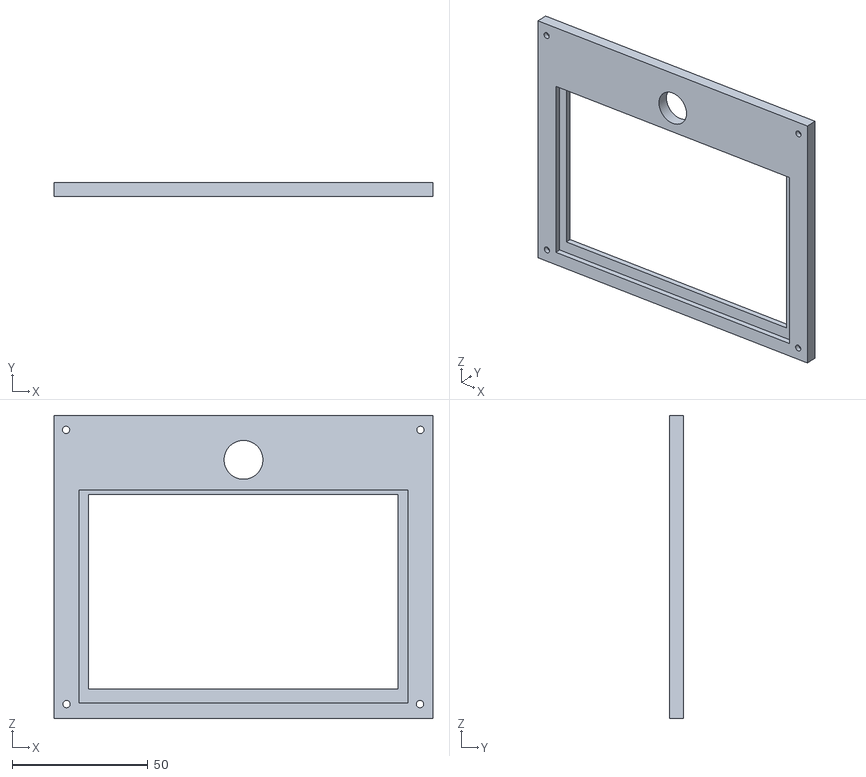
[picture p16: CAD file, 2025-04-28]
hw/cad_files/Front_Plate.stl
139.6 x 5.00 x 111.7

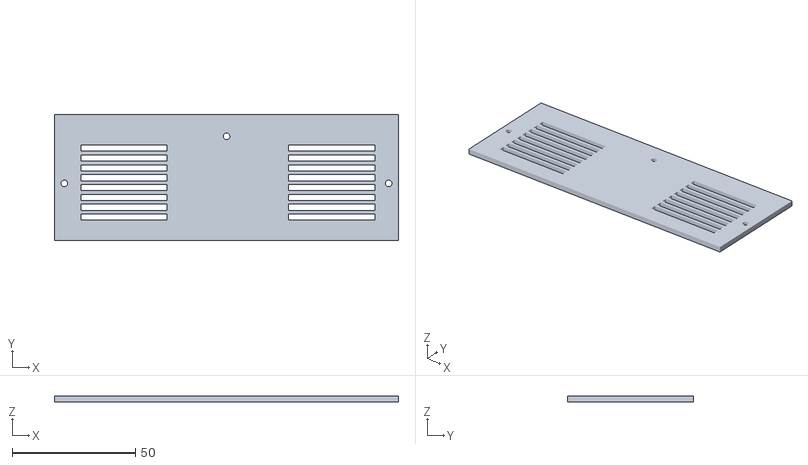
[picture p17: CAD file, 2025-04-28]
hw/cad_files/Lid.stl
139.6 x 51.3 x 2.50

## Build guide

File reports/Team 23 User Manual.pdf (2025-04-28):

## Boston University Electrical & Computer Engineering

EC464 Capstone Senior Design Project

## User's Manual

## Portable Language Translator

Team 23
Portable Language Translator

Team Members

Andrew Nguyen aynguyen@bu.edu
Cristian Palencia cris0211@bu.edu
Ryan Liao ryanliao@bu.edu
Yohan Kim yohank@bu.edu

Submitted: 4/18/2025

User's Manual | 1

### Portable Language Translator

Table of Contents

Executive Summary | 1
1. Introduction | 2
2. System Overview and Installation | 3
2.1. Overview block diagram | 3
2.2. User Interface. | 4
2.3. Physical description. | 4
2.4. Installation, setup, and support | 5
3. Operation of the Project | 7
3.1. Operating Mode 1: Normal Operation | 7
3.2. Operating Mode 2: Abnormal Operations | 7
3.3. Safety Issues | 7
4. Technical Background | 8
5. Relevant Engineering Standards | 9
6. Cost Breakdown | 11
7. Appendices | 12
7.1. Appendix A - Specifications | 12
7.2. Appendix B – Team Information | 13

Executive Summary
Communication is one of humanity’s most fundamental needs, yet language barriers and lack of widespread knowledge of ASL hinder our ability to connect. Our project aims to provide an all-in-one translation device that enables real-time translation between spoken languages and seamless conversation between ASL and speech. Our device will use speech recognition and translation, a camera, and a screen, all in a portable form factor to bridge communication gaps. It will enable users to engage in natural conversations, translating spoken words bidirectionally and interpreting ASL gestures into speech, fostering inclusivity and accessibility for diverse communities.
Team 23 Portable Language Translator | April 12, 2025

### 1. Introduction

In today’s increasingly interconnected world, language barriers continue to hinder effective communication—especially in situations where immediate understanding is crucial. This challenge is even more pronounced when it comes to American Sign Language (ASL), where accessible and seamless translation tools remain limited. While many devices exist to translate spoken language, few offer reliable solutions for interpreting ASL gestures, leaving a significant gap in support for the Deaf community. This project aims to bridge that gap with the Portable Language Translator, a device designed to recognize and translate both spoken language and ASL in real time.
One of the teams’ members, Andrew, previously worked at a popular matcha cafe. With some non-English speakers also visiting the cafe, it was difficult to give them the service they deserved in the time frame that is expected when the customer and Andrew did not understand each other. With the Portable Language Translator, this
communication would have been simplified and prevented any misunderstandings. This device is meant to help anyone in the service industry or anyone surrounded by people that don’t share their language.
Our approach integrates speech and image-based gesture recognition using a combination of hardware and software such as Google Cloud and machine learning. The portable translator uses a Raspberry Pi 5 along with a camera and microphone that captures user input. Spoken languages are transcribed using Google Cloud’s Speech-to-Text API and translated with Google Cloud’s Translation API. For ASL, we trained a Long Short-Term Memory (LSTM) model using TensorFlow to classify 5 different gestures (Hello, Thank You, Bathroom, Help and Yes), using OpenCV for video capture and MediaPipe to collect landmarks from the user’s hand and body. The TensorFlow model was converted into a TFLite model in order to host the model locally on the Raspberry and still have smooth performance. This approach solves a user’s key issue and enables real-time communication between speakers of different languages and even signers and non signers.
From a user’s perspective, several features of our project stand out. Our device allows for real-time ASL recognition as the camera captures hand gestures and classifies them with an 80%+ accuracy. Another feature of our device is the spoken language translation as the device will detect the spoken language between English, Spanish and Korean and translate into the user’s preferred language in under 2 seconds using cloud-based APIs. Our device enables hand-free communication as it is housed in a 3D enclosure that is worn with a pair of shoulder straps. Fluid communication is enabled as only one user needs to wear the portable device and text output is converted back to audio with text-to-speech conversion which removes the need to pass a device back and forth. Internet connectivity is required in order to use the spoken language translation as translation is done using Google Cloud’s APIs. While the system runs efficiently, the combined use of camera, microphone and wifi results in a battery life of about 3.125 hours.
The remaining sections in this manual will walk you through hardware components, set up instructions, software architecture and troubleshooting steps. Detailed diagrams and usage examples will help users understand how to use the Portable Language Translator.

### 2. System Overview and Installation

### 2.1. Overview block diagram

The PLT (Portable Language Translator) device is primarily held and contained within a physical encasing. The encasing provides mountings for the camera, microphone, and touch screen which all receive relevant input in the form as user interaction, ASL gestures, and language to be translated. All of these inputs are taken in by relevant hardware that is processed by a Raspberry Pi which handles translations that will be outputted in the form of visual text on the User Interface or audibly through the device’s speakers.

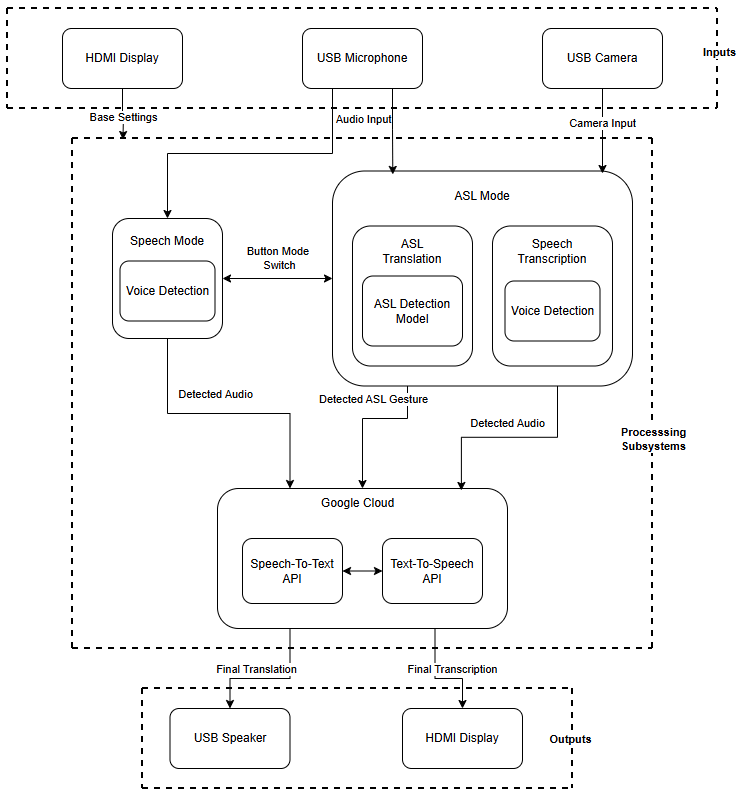
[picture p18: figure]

Figure 2.1 System Block Diagram

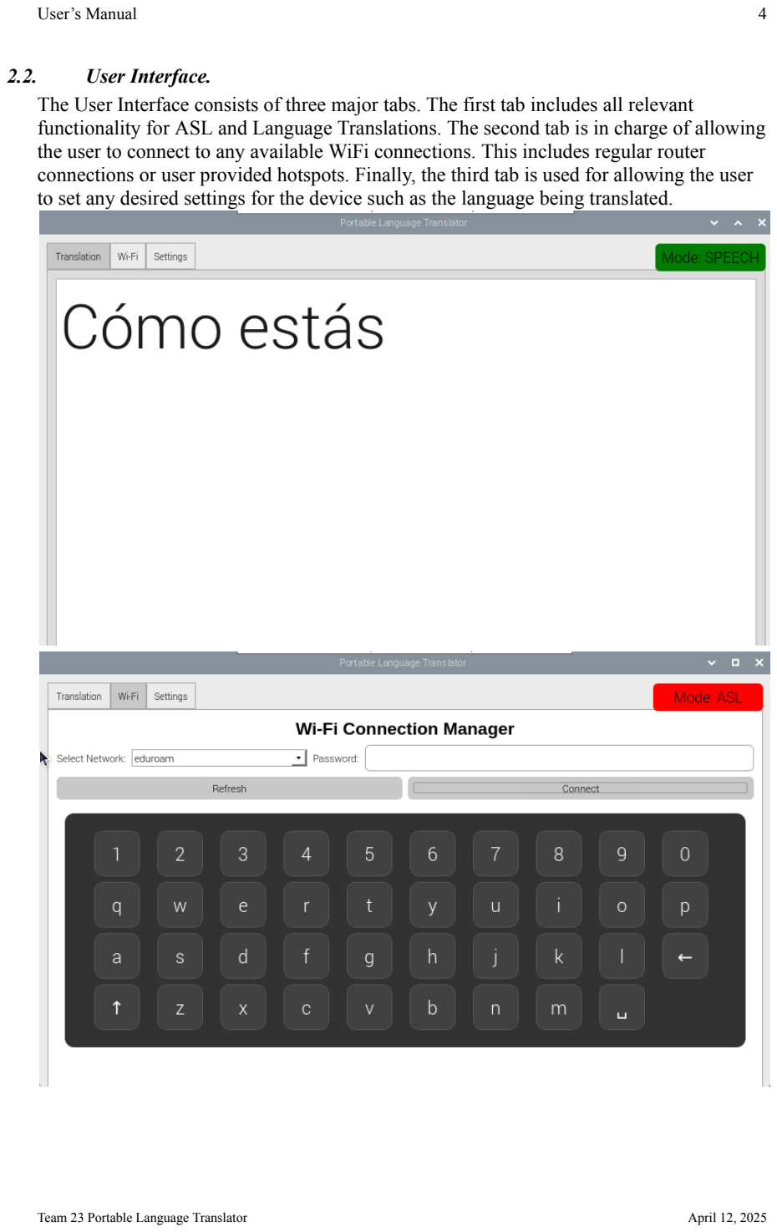
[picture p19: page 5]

User’s Manual | 4
2.2. User Interface.
The User Interface consists of three major tabs. The first tab includes all relevant functionality for ASL and Language Translations. The second tab is in charge of allowing the user to connect to any available WiFi connections. This includes regular router connections or user provided hotspots. Finally, the third tab is used for allowing the user to set any desired settings for the device such as the language being translated.

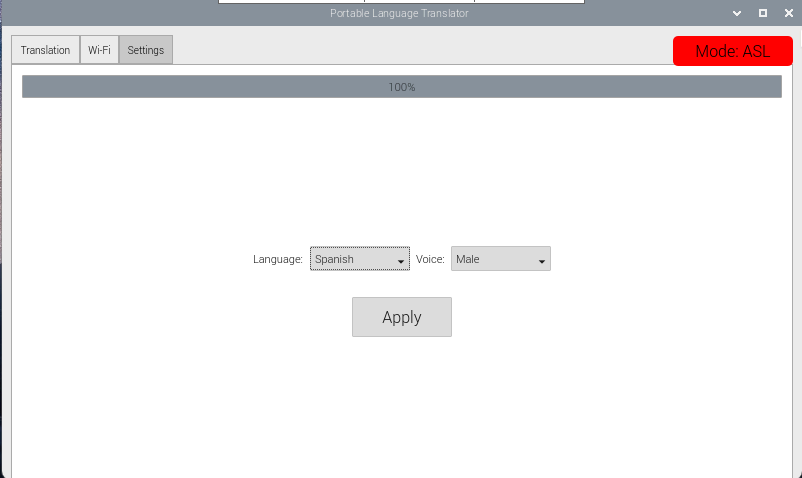
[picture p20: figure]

Figure 2.2 User Interface Tabular Organization

2.3. Physical description.
The device is composed of 3D printed components that mount the various components of the device. The device includes three components. One, the main frame directly allows the mounting of the Raspberry Pi, touch screen, and camera. Two, the back plate that permits ventilation and the mounting of the battery pack. Three, the top plate that encloses the system speakers. Finally, the user should be aware of the included straps that allow the device to be worn using shoulder support.

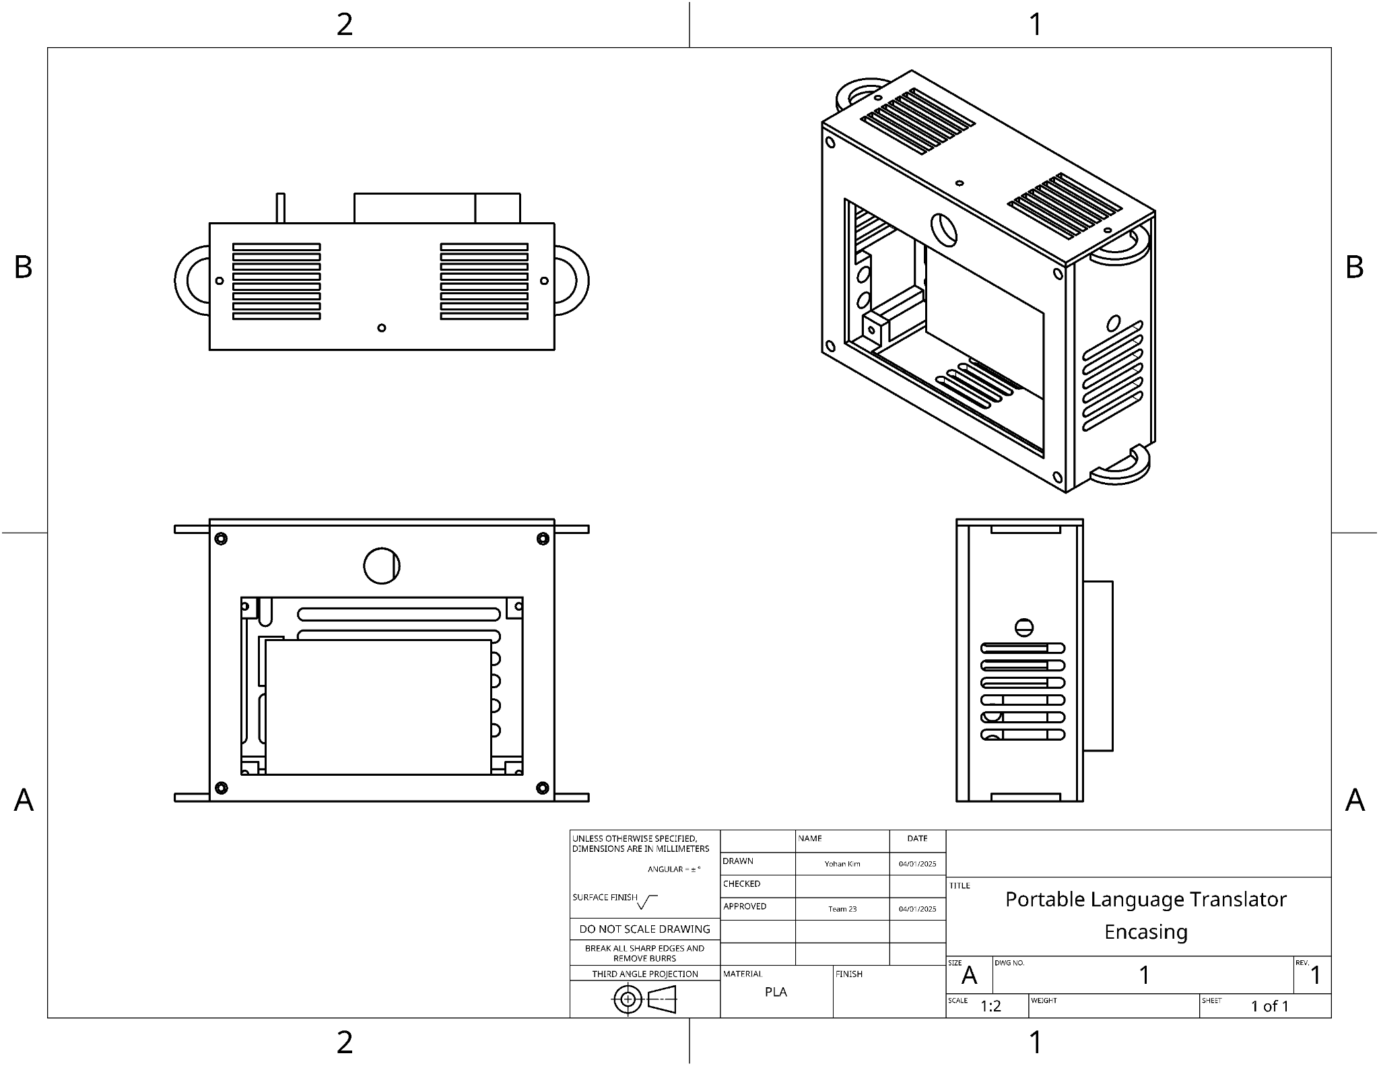
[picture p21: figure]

Figure 2.3 3D Drawings

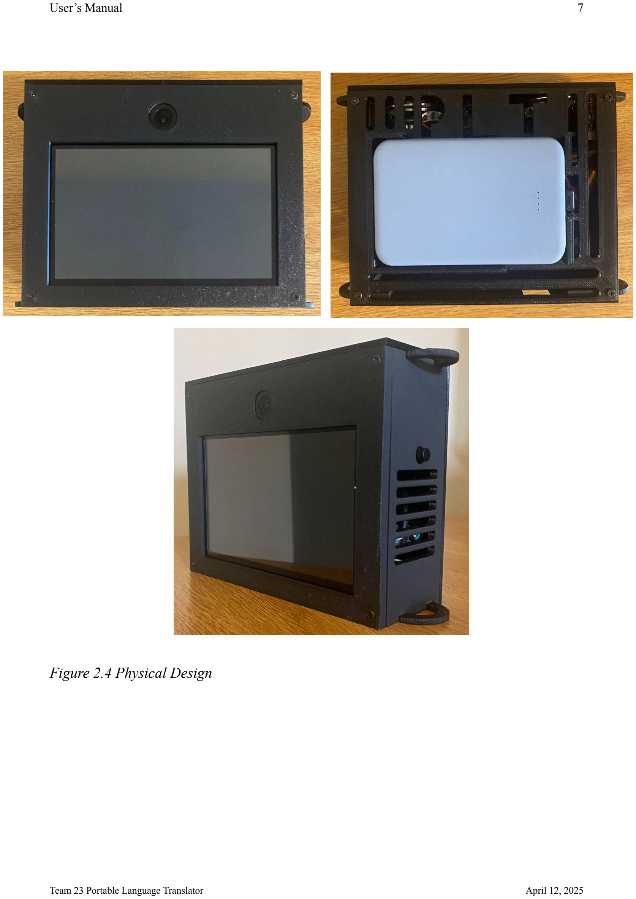
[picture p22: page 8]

Figure 2.4 Physical Design

### 2.4. Installation, setup, and support

Installation and Setup
Every PLT device already comes fully assembled along with all relevant software already included. Some relevant considerations when first obtaining the PLT include the following:
1) Battery pack charge: The included battery pack may not come charged already. If this is the case please use a micro-usb cable to connect to the battery pack and let it charge so that the device can properly operate.
2) Wearing the device: To put on the straps, start by clipping both straps onto the two bottom rings of the device. Then, take the bottom left strap and clip it onto the opposite top right ring. Next, put your left arm and head through the loop you’ve created. Finally, take the bottom right strap, bring it across your back and over your left shoulder, and clip it onto the top left ring. Adjust strap lengths as necessary.
3) Internet connection: The user needs to ensure that the device is connected to the internet. To do this please navigate to the second tab on the user interface and check for available networks that you may connect to.

### 3. Operation of the Project

3.1.Operating Mode 1: Normal Operation
In order to use the PLT:
1. Turn on the device by pressing on the power button on the battery pack once.
2. Once the device has turned on and the GUI has loaded, the language translation mode will be on by default.
3. Connect to the wifi network using the wifi tab by selecting a network and inserting a password if necessary using the touch screen.
4. Change desired settings in the settings tab using the touch screen again.
5. Once connected to wifi and updated the settings, the user is ready to use the device and may switch back to the Translation tab.
6. While in speech to speech mode, the user may speak and the device will start translating back and forth.
7. Press the button on the left side of the device to switch into ASL mode. The user can check which mode they are in with the indicator on the top right of the GUI.
8. While in ASL mode, the GUI will show the camera feed and start detecting ASL. Once the device finishes detecting, it will play the detected ASL gesture as speech. After the device finishes playing the audio, the GUI will switch to a text box and start listening for speech. After it has finished detecting speech, it will display the transcribed speech onto the text box. After 3 seconds, the GUI will switch back to the camera feed.
9. While using the device in either mode, the volume of the voice out can be adjusted with the two buttons on the right side of the device. The top button will raise the volume while the bottom button will decrease it.

### 3.2. Operating Mode 2: Abnormal Operations

One abnormal operation would be if the battery pack powering the device runs out of power and the device shuts off. If this happens, charge the battery pack and then reconnect the battery to the device when sufficient power is available. Next, turn the device back on by pressing on the power button once on the battery pack and the GUI will automatically load and the device will be ready to run once again. The device cannot operate while the battery is charging.
Another abnormal operation is the case of disconnection from the internet. If this happens, click on the wifi tab and reconnect to a network by selecting a wifi network and inserting a password if necessary using the onscreen keyboard. The device will be ready to translate once it has been reconnected.

### 3.3. Safety Issues

The device contains several openings for ventilation and access to hardware components such as the battery pack and cooling system. These openings are not sealed against moisture or water ingress. Exposure to rain, high humidity, or accidental splashes can lead to short circuits, damage to internal electronics, or even pose a fire or electric shock hazard. For safe operation, always use the device in dry, indoor environments and store it in a protective case when not in use.

### 4. Technical Background

### 4.1. Software Component

There are three major sections in the software component of the project: the language translation, ASL gesture recognition model, and the user interface software.

Language Translation:
The Language Translation subsystem processes spoken language inputs and converts them into another spoken language. The process begins by capturing audio using the systems usb microphone, which is processed in chunks to detect speech using the WebRTC VAD (Voice Activity Detection) library. This ensures that only relevant speech segments are processed. Once speech is detected, it is converted to text using Google Cloud's Speech-to-Text API. The text is then translated into the desired language using Google Cloud's Translation API. Finally, the translated text is synthesized into speech via Google Cloud's Text-to-Speech API, which is played back to the user through a USB speaker. This subsystem enables seamless bidirectional speech-to-speech communication between users speaking different languages.

ASL Gesture Recognition:
For the ASL gesture detection and prediction, the external camera (USB 2.0 Camera) will record a live video stream and the script will initialize this video feed with OpenCV. First processing camera frames is done with Mediapipe’s hand landmarks model to extract hand landmarks and then grouping these landmarks from the last 30 frames into a sequence. This sequence is fed into our LSTM (Long Short Term Memory) model that outputs the probability for each gesture. When a specific gesture’s confidence is greater than the threshold value, that gesture will be then chosen as the detected gesture. An asynchronous thread handles this inference process, ensuring that consistent and confident predictions are added to a running sentence, which is eventually converted into speech for translation. Once the sentence is done playing, the script will then listen for the audio and save the transcription in a .txt file where it will be displayed in the UI. Then the script will go back to detecting ASL gestures and the cycle will restart.

User Interface:
The user interface was programmed using a UI library called PyQt5. This allows us to create relevant UI objects that are linked to key components of the project. For example, it allowed the creation of labels, buttons, text boxes to support translations, wifi connectivity, and configuring relevant settings.

### 4.2. Hardware Component

The hardware for the project included several components including the Raspberry Pi 5, relevant USB devices (microphone, speaker, and camera), touch screen, and battery.

Raspberry Pi 5
The Pi 5 acts as the main processing unit of our project. It handles receiving relevant input from the USB devices and by interfacing directly with the touchscreen display. It includes relevant software for processing the inputs to be either translated or recognized as a gesture. Afterwards it handles properly outputting to either the system's speakers or back onto the touchscreen.

Microphone
USB device connected to the Pi. It allows the users to speak directly into the device for appropriate translation.

Speaker
USB device connected to the Pi. Outputs relevant translation processed by the Raspberry Pi

Camera
USB device connected to the Pi. When in gesture recognition mode it reads in the camera feed such that the Pi can process supported ASL gestures

Touch Screen
Connected directly to the Raspberry Pi such that the user can interact with user interface for wifi connectivity and settings via touch input.

Battery
The battery pack is mounted to the back of the device and provides the devices with at least 3.125 hours of battery life at max performance.

### 4.3. Physical Component

The 3D print allows the user to interact directly with different components of the device. Specifically. it allows the user to interact with the touch screen along with three relevant buttons on the side of the device. The three included buttons are the volume control (two buttons for volume up and volume down) and one button for mode toggling between ASL translation mode and Language translation mode.

### 5. Relevant Engineering Standards

The Portable Language Translator was developed with both industry standards and real world engineering practices in mind. This section outlines the most relevant hardware, software, communication and usability standards that were applied during development. Each contributed to the system’s accuracy, safety and user accessibility. These standards were reinforced through testing, iteration and refinement. By intentionally aligning the Portable Language Translator with these standards, the team ensures that the product is secure, scalable, portable and accessible while upholding the best practices in electrical, software and systems engineering.

Hardware and Electrical Standards
- IEC 62368-1 - Audio/Visual and ICT Equipment Safety
Applied to the Raspberry Pi 5, which powers the USB peripherals (camera, speaker, microphone and HDMI Display) safely within low-voltage design limits. Power draw was tested at 1.6A and a 5000mAh battery supports up to 3.125 hours of safe runtime which exceeds the 2 hour design requirement.
- IEEE 802.11 - Wifi Communication
The device connects securely to the internet through a user’s phone hotspot using a touchscreen-based virtual keyboard. This allows for secure transmission of audio/image data to cloud services.

Software Engineering and Machine Learning Standards
- PEP 8 - Python Code Style
Used throughout the development of scripts managing gesture recognition (OpenCV, MediaPipe, TensorFlow) and speech processing (Google Cloud APIs), improving readability and collaborative debugging.
- IEEE 829 - Test Documentation
Formal testing of both spoken language and ASL recognition was structured in tabulated accuracy/error reports.
- TensorFlow Training Guidelines
ML model training followed recognized practices: using sufficient training epochs, a clear confidence threshold and asynchronous threading to separate inference from data collection.

Accessibility and Human Interface Standards
- Section 508 Compliance
This project was built with inclusivity in mind. The Portable Language Translator converts gestures to spoken language and spoken phrases to text. This device is usable by individuals who are deaf, hard of hearing or non-verbal.
- W3C Web Accessibility Initiative (WAI)
The UI tab on the built-in touch display allows users to configure key settings such as base language and voice gender. The interface was designed following accessibility aware practices, including clear labeling, intuitive layout and touch-friendly elements to ensure usability for individuals with disabilities. While not web based, the UI adheres to core WAI principles.

Operating System and File Standards
- POSIX Compliance
The Raspberry Pi 5 runs a Linux operating system, which is POSIX compliant. This ensures robust scripting with predictable file permission and process control and compatibility with standard tools for logging, threading and scheduling.

### 6. Cost Breakdown

Project Costs for Production of Beta Version (Next Unit after Prototype)
Item | Quantity | Description | Unit Cost | Extended Cost
1 | 1 | Raspberry Pi 5 | 84.99 | 84.99
2 | 1 | Raspberry Pi 5 Active Cooler | 4.99 | 4.99
3 | 1 | Touch Screen | 32.99 | 32.99
4 | 1 | Microphone | 4.50 | 4.50
5 | 1 | Speaker | 13.99 | 13.99
6 | 1 | Camera | 14.99 | 14.99
7 | 1 | Battery Pack | 8.45 | 8.45
8 | 1 | Shoulder Straps | 17.98 | 17.98
Beta Version-Total Cost | | | | 182.88
Table 6.1 Cost breakdown

### 7. Appendices

### 7.1. Appendix A - Specifications

Specification | Value, Range, Tolerance, Units
Case Dimensions | 167.6 mm x 43.8 mm x 111.7 mm
Power | 5000 mAh battery pack
Latency (Speech) | < 3 sec
Latency (ASL) | < 3 sec
Speech Detection Range | 50 - 70 dB within 1 m
ASL Detection Range | 1 m
Battery Life | 3.125 hours

### 7.2. Appendix B – Team Information

Cristian Palencia
I am a Computer Engineering major from Framingham, Massachusetts. From a relatively young age I’ve always enjoyed working with computers and computer parts. For that reason I decided to go into Computer Engineering in college and pursue a career that allows me to dive deeper into those interests. Specifically, throughout my time in Boston University I have discovered a main interest in Embedded Systems. For this reason I have posed myself as such for our project. I enjoy working with hardware components and being able to write code to actualize them.

Contact Information
- email: cris0211@bu.edu
- phone: 508-630-6468

Andrew Nguyen
I am a Computer Engineering major with an emphasis on full-stack development, machine learning, and computer graphics. I am passionate about technology as a whole but I am really interested in games and VR.

Contact Information:
- email: aynguyen@bu.edu

Yohan Kim
I am a senior majoring in Computer Engineering. Throughout my college career I have been interested in software engineering with an emphasis on backend engineering. I am passionate about creating impactful solutions and continuously expanding and learning new skills in the area of software engineering.

Contact Information
- email: yohank@bu.edu
- phone: 408-809-6250

Ryan Liao
I am a senior Computer Engineering student pursuing a concentration in Machine Learning from Beacon, NY. I want to use my experiences from college to create solutions that drive positive societal impact.
Contact Information
- email: ryanliao@bu.edu
- phone: 845-542-8689

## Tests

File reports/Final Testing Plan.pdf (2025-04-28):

# Boston University Electrical & Computer Engineering

EC 464 Senior Design Project

## Final Testing Plan

Portable Language Translator


By

Team 23

Portable Language Translator

Team Members

Yohan Kim yohank@bu.edu
Ryan Liao ryanliao@bu.edu
Cristian Palencia cris0211@bu.edu Andrew Nguyen aynguyen@bu.edu

Required Materials:
Software
- Language Translation
- Google Cloud Platform project with text-to-speech, speech-to-text, translate, and storage API’s
- Python3 Packages:
■ Numpy
■ Sounddevice
■ Google-cloud-speech
■ Google-cloud-texttospeech ■ Google-cloud-translate
■ Webrtcvad
■ Pydub
■ simpleaudio
■ Pynput
- ASL Detection Model
- Python3 Packages
■ OpenCV
■ Tensorflow
■ Mediapipe
■ Numpy
- User Interface
- Python3 Packages
■ PyQt5
- Firmware
- Python3 Packages
■ gpiozero

Hardware
- Raspberry Pi 5
- USB Devices
- USB Camera
- USB Speaker
- USB Microphone
- Portable Power Bank (5000 mAh)
- Touch Display
- 3 Buttons (Audio control and Mode toggling)
- Encasing (3D print)

Set Up:
For the hardware setup we have a Raspberry Pi 5 that interfaces with all the relevant components. Specifically, it interfaces with the following: USB camera, USB speaker USB microphone and a touch display all of which are mounted throughout the 3D printed encasing. The Raspberry Pi will be connected to the user’s phone hotspot using 1 of 3 UI tabs where a user can select their internet and insert their password through a virtual keyboard displayed on the touch display.
For the language translation, a dedicated UI tab allows users to configure settings for the language translation, such as, base language and voice gender before the translation starts. One device is used for the conversation. The users must wait for the translation and playback to fully finish before beginning the next phrase. The program captures audio from the USB microphone, splits it into chunks and uses voice activity detection software to determine if someone is speaking. Once it detects no speech, it sends the audio file to the google cloud for the transcription, translation, and finally text-to-speech. The audio file is sent back to the program which it plays from the system’s speaker and to display the translated text on the translation UI tab.
For the ASL gesture detection and prediction, the external camera (USB 2.0 Camera) will record a live video stream and the script will initialize this video feed with OpenCV. First processing camera frames is done with Mediapipe’s hand landmarks model to extract hand landmarks and then grouping these landmarks from the last 30 frames into a sequence. This sequence is fed into our LSTM (Long Short Term Memory) model that outputs the probability for each gesture. When a specific gesture’s confidence is greater than the threshold value, that gesture will be then chosen as the detected gesture. An asynchronous thread handles this inference process, ensuring that consistent and confident predictions are added to a running sentence, which is eventually converted into speech for translation. Once the sentence is done playing, the script will then listen for the audio and save the transcription in a .txt file where it will be displayed in the UI. Then the script will go back to detecting ASL gestures and the cycle will restart.

Pre-Testing Setup Procedure:
Preliminary Hardware Setup:
1. Connect relevant USB devices including microphone, speaker, and camera.
a. To properly setup the microphone and speaker control on the Pi we need to run the following: sudo apt install alsa-utils
2. Connect touch screen display via DSI.
3. Connect three buttons to GPIO pins 4, 17, and 27. Additionally, connect the other terminals to ground.
4. Mount the display / Raspberry Pi to the encasing using screws.
5. Glue down the speaker devices onto the appropriate location on the encasing.
6. Fasten the camera in the provided slot at the top of the encasing.
7. Connect the Raspberry Pi to the power bank using a usb cable.
8. Place the back plate onto the device and screw into place.
9. Turn on the power bank using the opening on the encasing.

Initial Setup:
1. Install dependencies using: “pip install -r requirements.txt”
2. Run the script “python3 everything.py”

Testing Procedure:
1. Connect to mobile hotspot.
2. Start in Language Translation mode. Have a conversation switching between english, spanish, and/or korean (change using settings tab). Also, we can press the volume control buttons to modify volume out.
a. English - Spanish script: (male)
i. ¿Hola, como estas? (Hello, how are you?)
ii. | I am very good thank you! How was your day?
iii. | ¡Mi dia a sido bueno! ¿Que comiste hoy? (My day has been good! What
| did you eat today?)
iv. | I ate a hamburger and drank water
b. Spanish - Korean script: (female)
i. ¿Hola, como estas? (Hi, how are you?)
ii. | 나는 오늘 좋았어 고마워 너는 어땠어 (I am good, thank you! How was
| your day?)
iii. | ¡Mi dia a sido bueno! (My day has been good!)
iv. | ¿Que comiste hoy? (What did you eat today?)
v. 나는 햄버거를 먹고 물을 마셨어 (I ate a hamburger and drank water)
3. Press the mode toggle button to switch to ASL mode.
4. Go through ASL script a. ASL: hello help bathroom
b. Speech: Yes the bathroom is down the hall, will you get there ok?
c. ASL: Yes, thanks
d. Speech: Have a nice day
5. Press the mode toggle button to switch back to Language Translation mode
6. Press power button to turn off device

Measurable Criteria:
Language:
I. Device is able to translate between the set base language of English, Spanish or Korean and the other detected language.

ASL:
I. Camera is able to detect ASL hand gestures, form a sentence, and translate them to words
II. | Words translated from ASL will be spoken aloud from the speaker.
III. | The program will automatically switch from using the camera to detect hand gestures to
| listening for speech.
IV. | Spoken words will be transcribed and displayed on the on-screen UI as well as a live
| view of the camera feed.
V. The program will go back to detecting ASL hand gestures automatically after spoken
| words are displayed on UI.

User Interface:
I. Displays relevant text translation to the user
II. | Demonstrates camera live feed such that the user can position themselves properly in the
| view of the camera.
III. | Settings are able to be sent from the dedicated UI tab on the display.
IV. | Users can use the Wifi tab to connect the device to their phone hotspot.

Hardware / Firmware:
I. Three buttons are fully functional. One button is in charge of toggling between ASL and
| Language Translation modes. The other two are in charge of adjusting the volume of the
| speaker.
II. | USB microphone properly picks up audio
III. | USB speaker outputs audio when necessary and can clearly be heard by users.

Score Sheet:

Test | Correct?

English - Spanish conversation

Able to translate same language in succession

Spanish - Korean conversation

ASL - Form a sentence from gesture

ASL - Audio transcribes onto UI

Button - Mode Toggling

Buttons - Volume Control

Device Wearability

Independent of Wall Brick

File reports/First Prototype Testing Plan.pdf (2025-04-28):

# Boston University Electrical & Computer Engineering

EC 463 Senior Design Project

## First Prototype Testing Plan

Portable Language Translator


By

Team 23

Portable Language Translator

Team Members

Yohan Kim yohank@bu.edu
Ryan Liao ryanliao@bu.edu
Cristian Palencia cris0211@bu.edu Andrew Nguyen aynguyen@bu.edu

Required Materials:
Software:
- Language Translation
- Google Cloud Platform project with text-to-speech, speech-to-text, translate, and storage API’s
- Python3 Packages:
- Numpy
- Sounddevice
- Google-cloud-speech
- Google-cloud-texttospeech
- Google-cloud-translate
- Webrtcvad
- Pydub
- Pynput
- Flask
- Flask-cors
- ASL Detection Model
- Python3 Packages
- OpenCV
- Tensorflow
- Mediapipe
- Google-generativeai
- User Interface
- Python3 Packages
- PyQt5
- Firmware
- Python3 Packages
- Adafruit_ssd1306
- PIL
- Pygame
- Sounddevice
- Numpy
- scipy.io.wavfile

Hardware:
- Raspberry Pi 3
- I2S MEMS Adafruit Microphone
- USB 2.0 Speaker

- OLED Display (ssd1309 driver) - Microusb Power Supply

Set Up:
For the language translation, a react web app is used to control the base language and voice settings of the program, which it sends using a flask api. One device is used for the conversation. The users must wait for the translation and playback to fully finish before beginning the next phrase. The program captures audio, splits it into chunks and uses voice activity detection software to determine if someone is speaking. Once it detects no speech, it sends the audio file to the google cloud for the transcription, translation, and finally text-to-speech. The audio file is sent back to the program which it plays from the system’s speaker.
For the ASL detection, the external camera (USB 2.0 Camera) will record a live video stream and the script will initialize the video feed. Mediapipe Hands will detect the hand in the video feed and locate 21 key landmarks along the user’s hand which are then normalized and prepared for classification. The keypoints are passed into the KeyPointClassifier, which is a pre-trained ML model that matches the keypoints to an ASL alphabet gesture. Each frame is checked to identify the letter being signed and the predicted letter is displayed on the laptop screen. If the signed label is held stable for .75 seconds then the detected letter will be put into the detected string. The user will consecutively sign letters until their word is complete. Once 2 seconds have passed, the detected string will be updated into the word list and the user may continue signing their next word if needed. Once the user has stopped signing their sentence for 3 seconds, the finalized word list/sentence is moved into a txt file.
For the hardware setup we have a Raspberry Pi that interfaces with all the relevant components. For one, we use the GPIO pins to connect to the SPI interface for the OLED display. The OLED display interfaces with the adafruit_ssd1309 library to send over the appropriate signals over the GPIOs and uses PIL to allow for relevant drawing capabilities to the OLED. Additionally, we have our I2S MEMS microphone also connected to the Pi’s GPIO pins. The microphone directly interfaces with the sounddevice library which handles reading from a connected I2S audio device such that we can generate a .wav file recording. Finally, we have a USB 2.0 Speaker that, using the pygame library, can output the audio recorded by the microphone, or any provided .wav file.

Pre-Testing Setup Procedure:
Initial Setup:
1. Install dependencies using: “pip install -r requirements.txt”

For Language Translation:
1. Run the react app using: “npm run dev”
2. Run the script using: “python \main.py”

For ASL Translation:
1. Run ASL detect script using “python detect.py”

For Raspberry Pi Hardware Test:
1. First enable the following interfaces on the Raspberry Pi
a. SSH: allows remote connection to the Pi such that we can execute commands from an alternative terminal
b. SPI: allows communication to the OLED display
c. I2S: allows the use of the microphone
2. With SSH enabled, we can connect to the Raspberry Pi using plt@<ip_addr>
3. Once we are connected we can navigate to the directory with our fw code.
4. Once we are here we can activate our virtual environment (contains all of our dependencies) using source ~/Documents/ec463/sd/fw/venv/bin/source
5. Run python3 hardware_test.py to run the test that integrates all relevant hardware

Testing Procedure:
Language Translation:
1. Run the scripts
2. Set the base language, voice gender and type on web app and press confirm to send settings. This will change what language the program translates to and what voice it uses for the translation.
3. Have a conversation switching between english, spanish, and/or korean
a. English - Spanish script: (male)
i. ¿Hola, como estas? (Hi, how are you?)
ii. | I am very good thank you! How was your day?
iii. | ¡Mi dia a sido bueno! ¿Que comiste hoy? (My day has been good! What
| did you eat today?)
iv. | I ate a hamburger and drank water
b. English - Korean script: (male)
i. 병원 어디 있어? (Where is the hospital?)
ii. | It is just down the street
iii. | Do you need help getting there?
iv. | 병원 얼마나 멀어요? (How far is your hospital?)
v. It should take you 15 minutes to walk there
c. Spanish - Korean script: (female)
i. ¿Hola, como estas? (Hi, how are you?)
ii. | 나는 오늘 좋았어 고마워 너는 어땠어 (I am good, thank you! How was
| your day?)
iii. | ¡Mi dia a sido bueno! (My day has been good!)
iv. | ¿Que comiste hoy? (What did you eat today?)
v. 나는 햄버거를 먹고 물을 마셨어 (I ate a hamburger and drank water)

ASL Translation:
1. Run the script
2. See if the model is capable of accurately translating ASL letters into phrases (ASL to English).
3. Test the following phrases:
a. Hello my name is Yohan
b. The car is red
4. Translated sentences will be stored in a txt file that will be used for audio output.

Hardware Test:
1. Run the script off of the Raspberry Pi
2. Start recording audio from the microphone
a. OLED should display that the test has started and that the recording has started
b. OLED will also notify us once the recording has stopped (5 seconds)
3. Save to audio file (output.wav)
a. Once again OLED display will notify us of this
4. Finally, output .wav file to the usb speaker
a. Final OLED display notification

Measurable Criteria:
Language Translation:
- React app should successfully run and have options for base settings
- Settings should accurately change the voice and base language of the program
- User should be able to have a bilingual conversation between two parties relatively seamlessly without manual input
- Speech to Speech latency is under 5 seconds

ASL Translation:
- ML model should be able to detect ASL letters using the camera module, not laptop camera.
- Model should be able to detect individual letters and create a sentence in English.
- Model should be able to translate ASL with at least 90% accuracy.

Hardware Test:
- Microphone
- We should be able to see that the microphone is able to record quality audio.
- Less dependent on capable distance for prototype since we can amplify the signal as needed later on
- Speaker
- Verify microphone capabilities with a USB 2.0 Speaker. Additionally, reference point for using other USB speakers in the future parts of the project
- OLED
- Should be able to be written to at a fast speed
- Readable text

Score Sheet:

Test | Correct?

English - Spanish conversation

Transitions to next conversation w/o manual input

English - Korean conversation

Able to translate same language in succession

Spanish - Korean conversation

ASL - Hello my name is Yohan

ASL - The car is red

Hardware Pinout

Pi3 Pin # | Usage / Description
1 | 3.3V Power to Microphone
2 | 5V Power to OLED
6/9 | GND
12 | GPIO1 → BCLK for Microphone
18 | GPIO24 → DC for OLED
19 | GPIO12 → MOSI for OLED
22 | GPIO25 → RST for OLED
23 | GPIO14 → CLK for OLED
24 | GPIO8 → CS for OLED
35 | GPIO24 → LRCL for Microphone
38 | GPIO28 → DOUT for Microphone

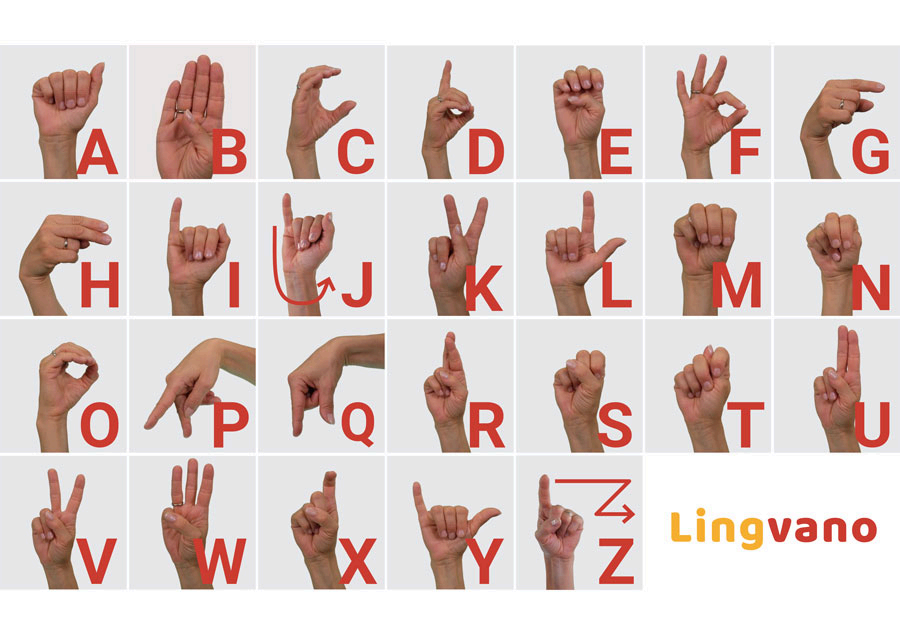
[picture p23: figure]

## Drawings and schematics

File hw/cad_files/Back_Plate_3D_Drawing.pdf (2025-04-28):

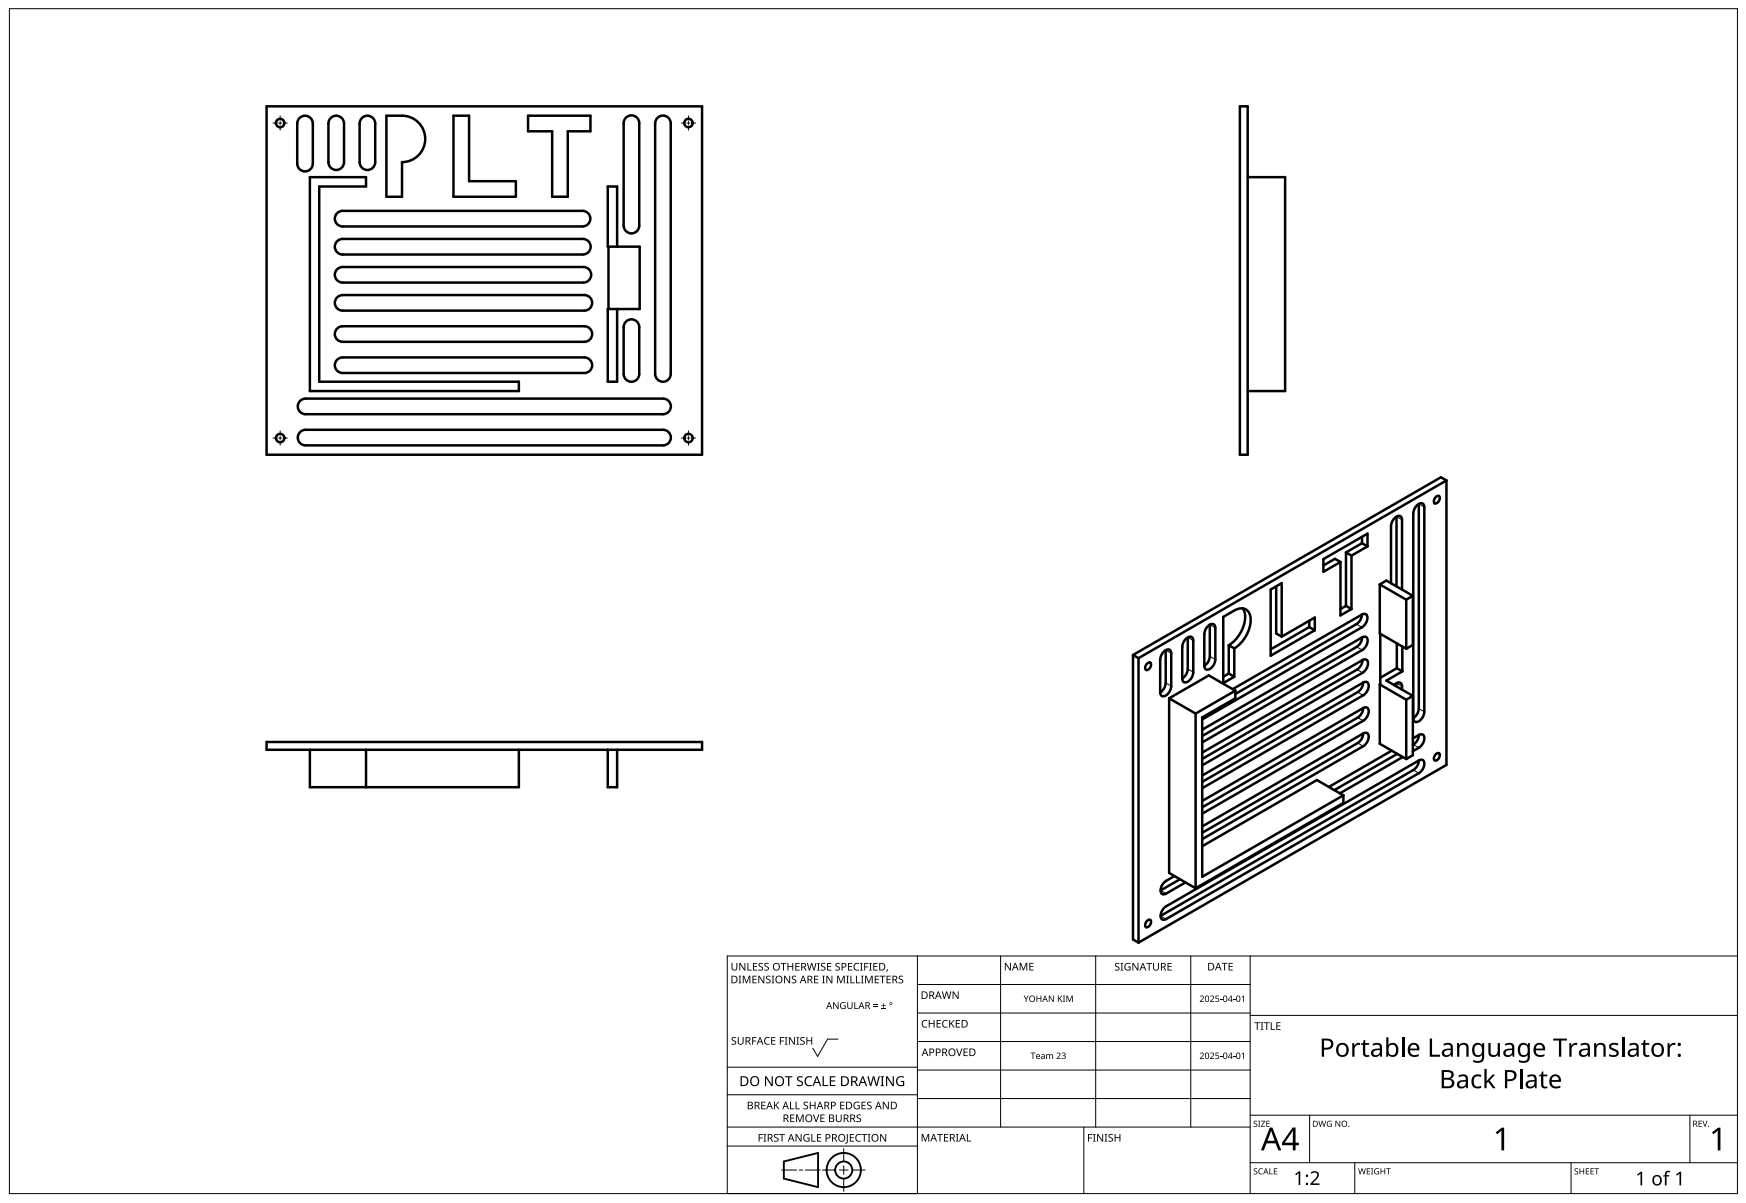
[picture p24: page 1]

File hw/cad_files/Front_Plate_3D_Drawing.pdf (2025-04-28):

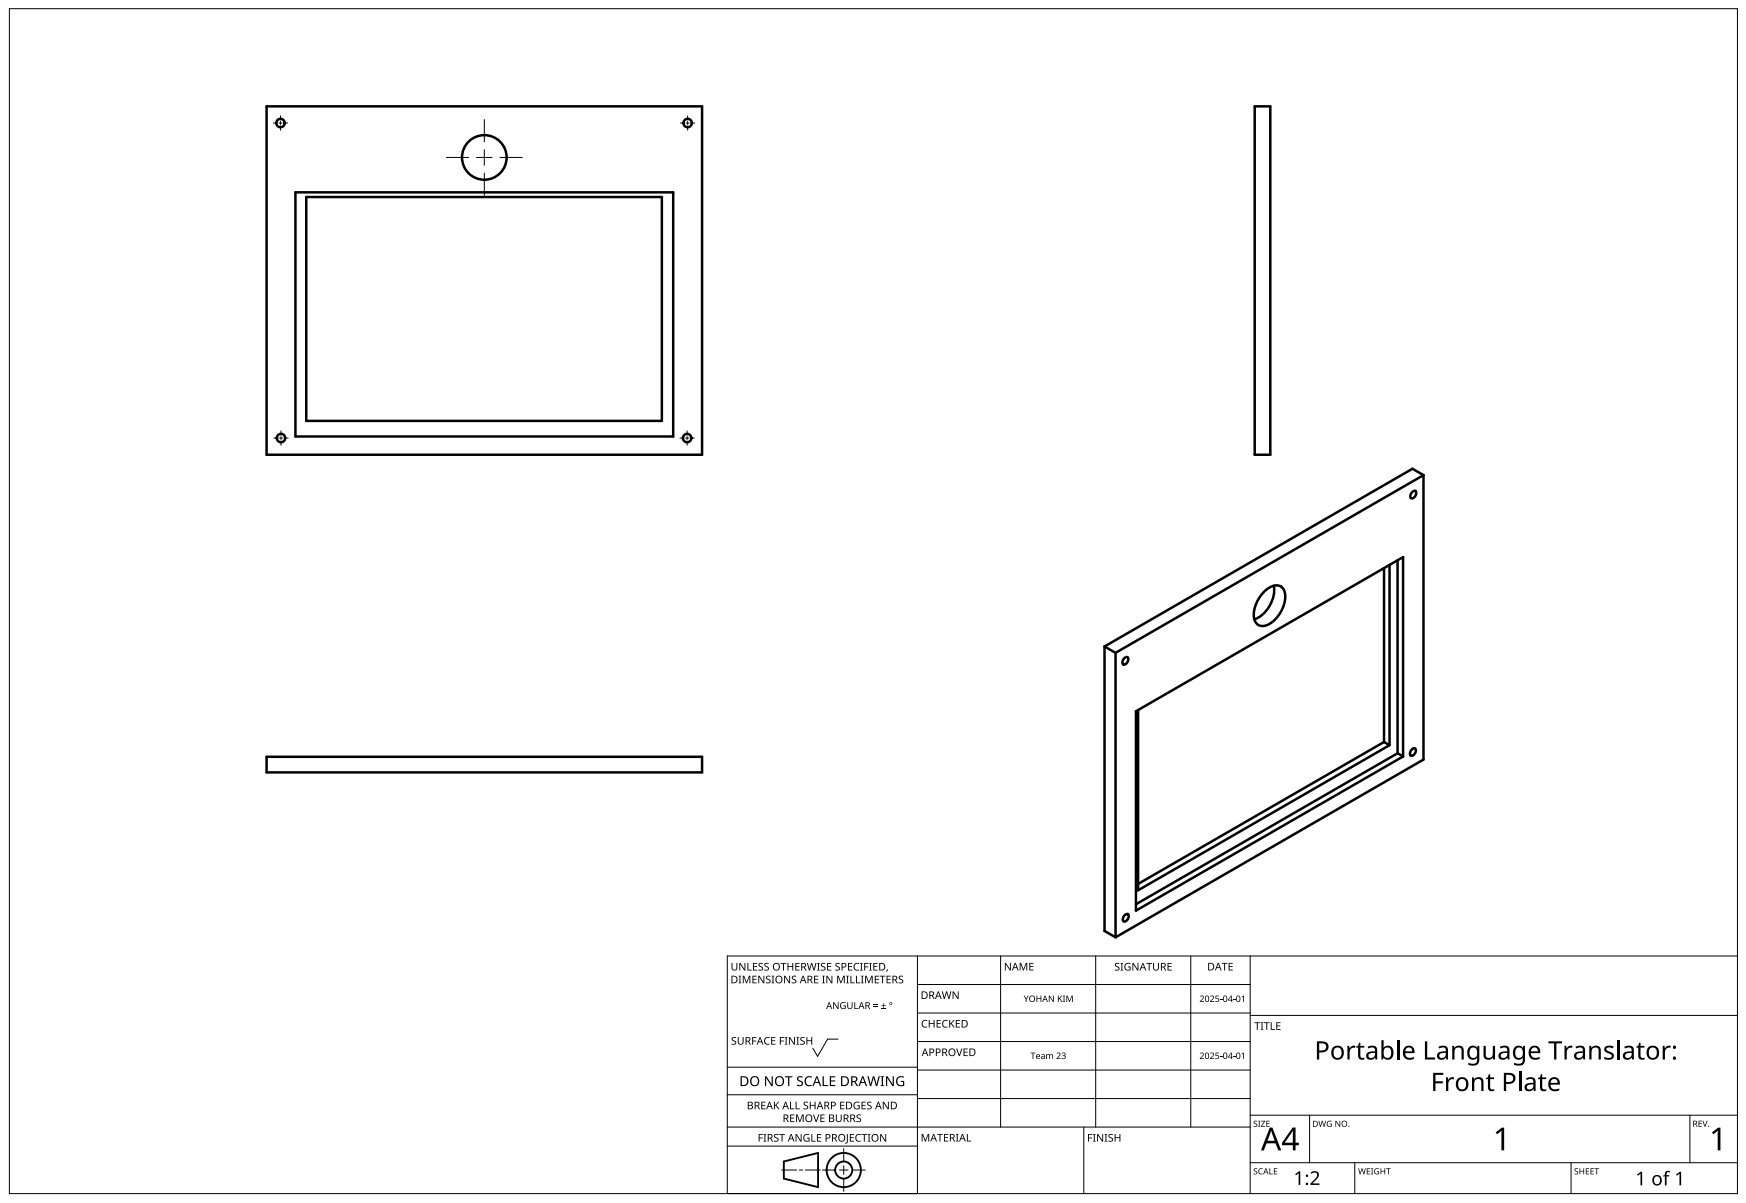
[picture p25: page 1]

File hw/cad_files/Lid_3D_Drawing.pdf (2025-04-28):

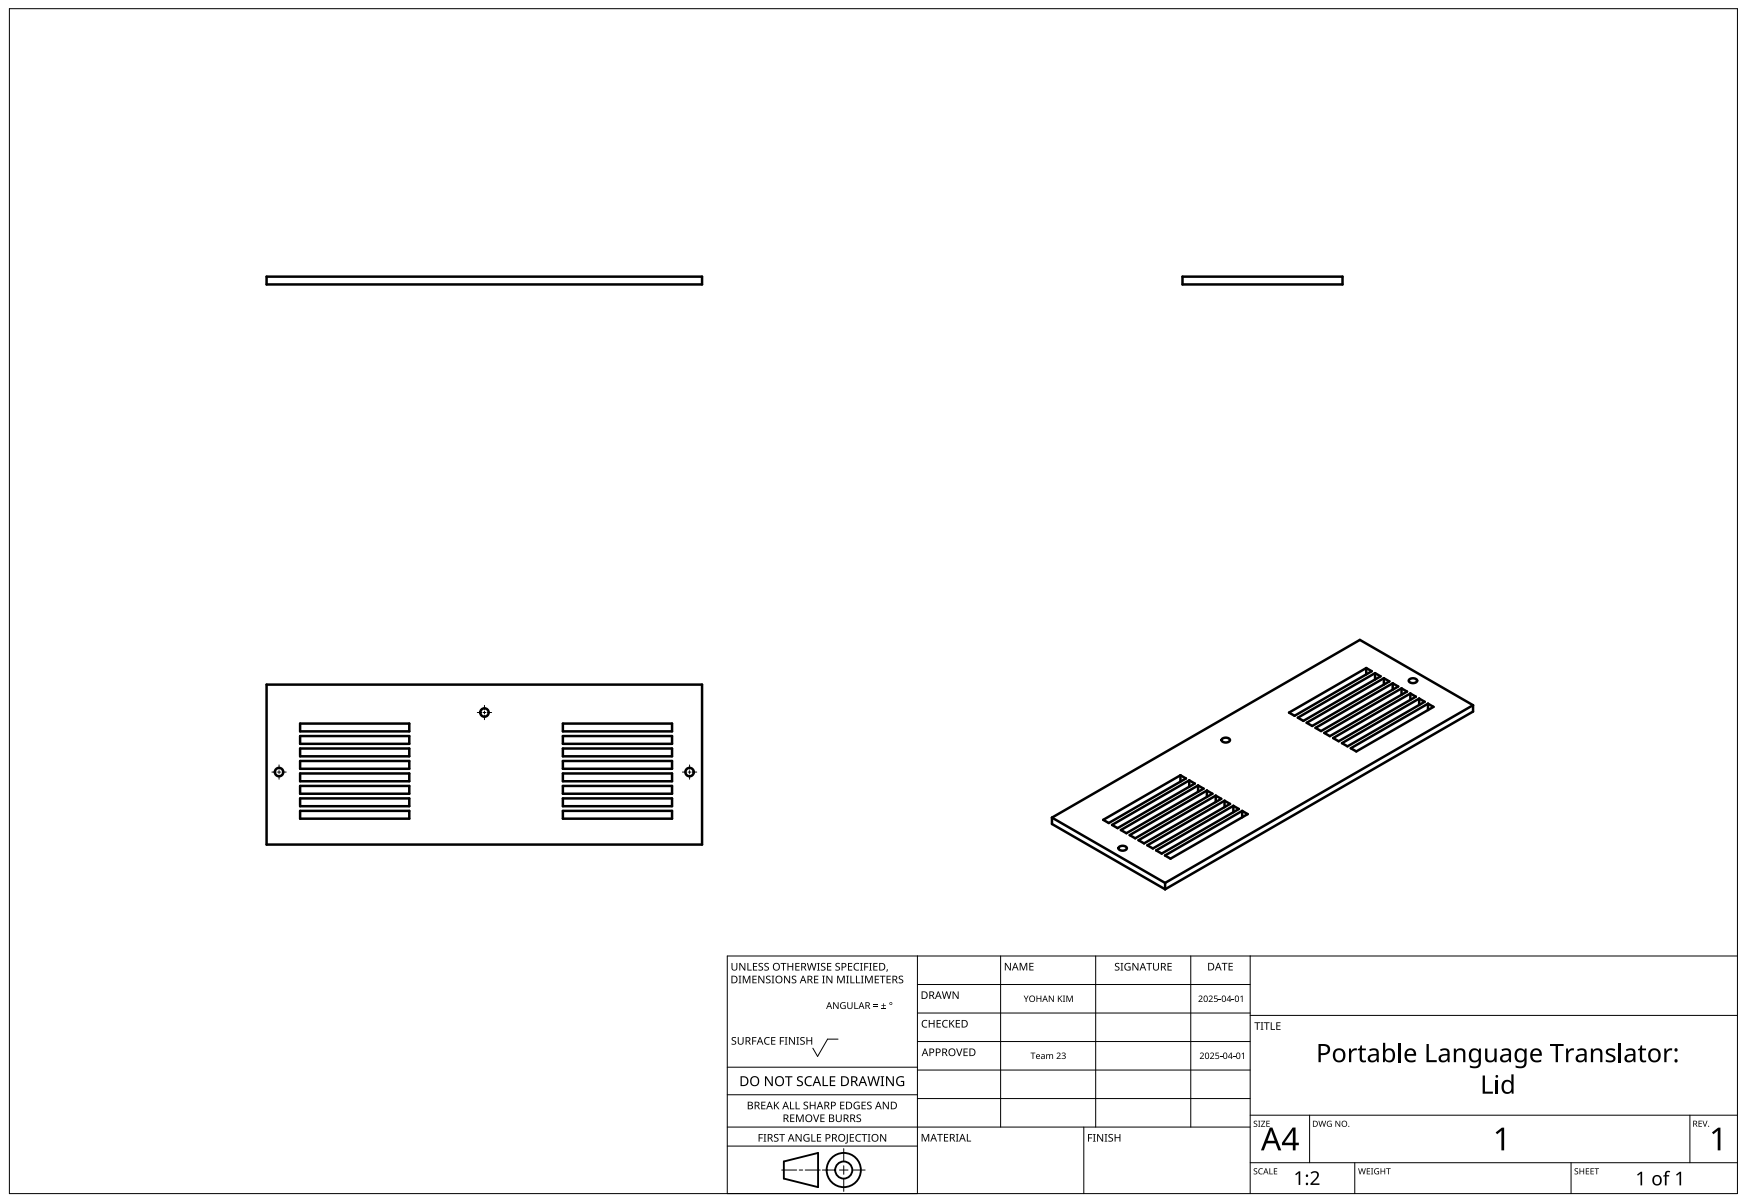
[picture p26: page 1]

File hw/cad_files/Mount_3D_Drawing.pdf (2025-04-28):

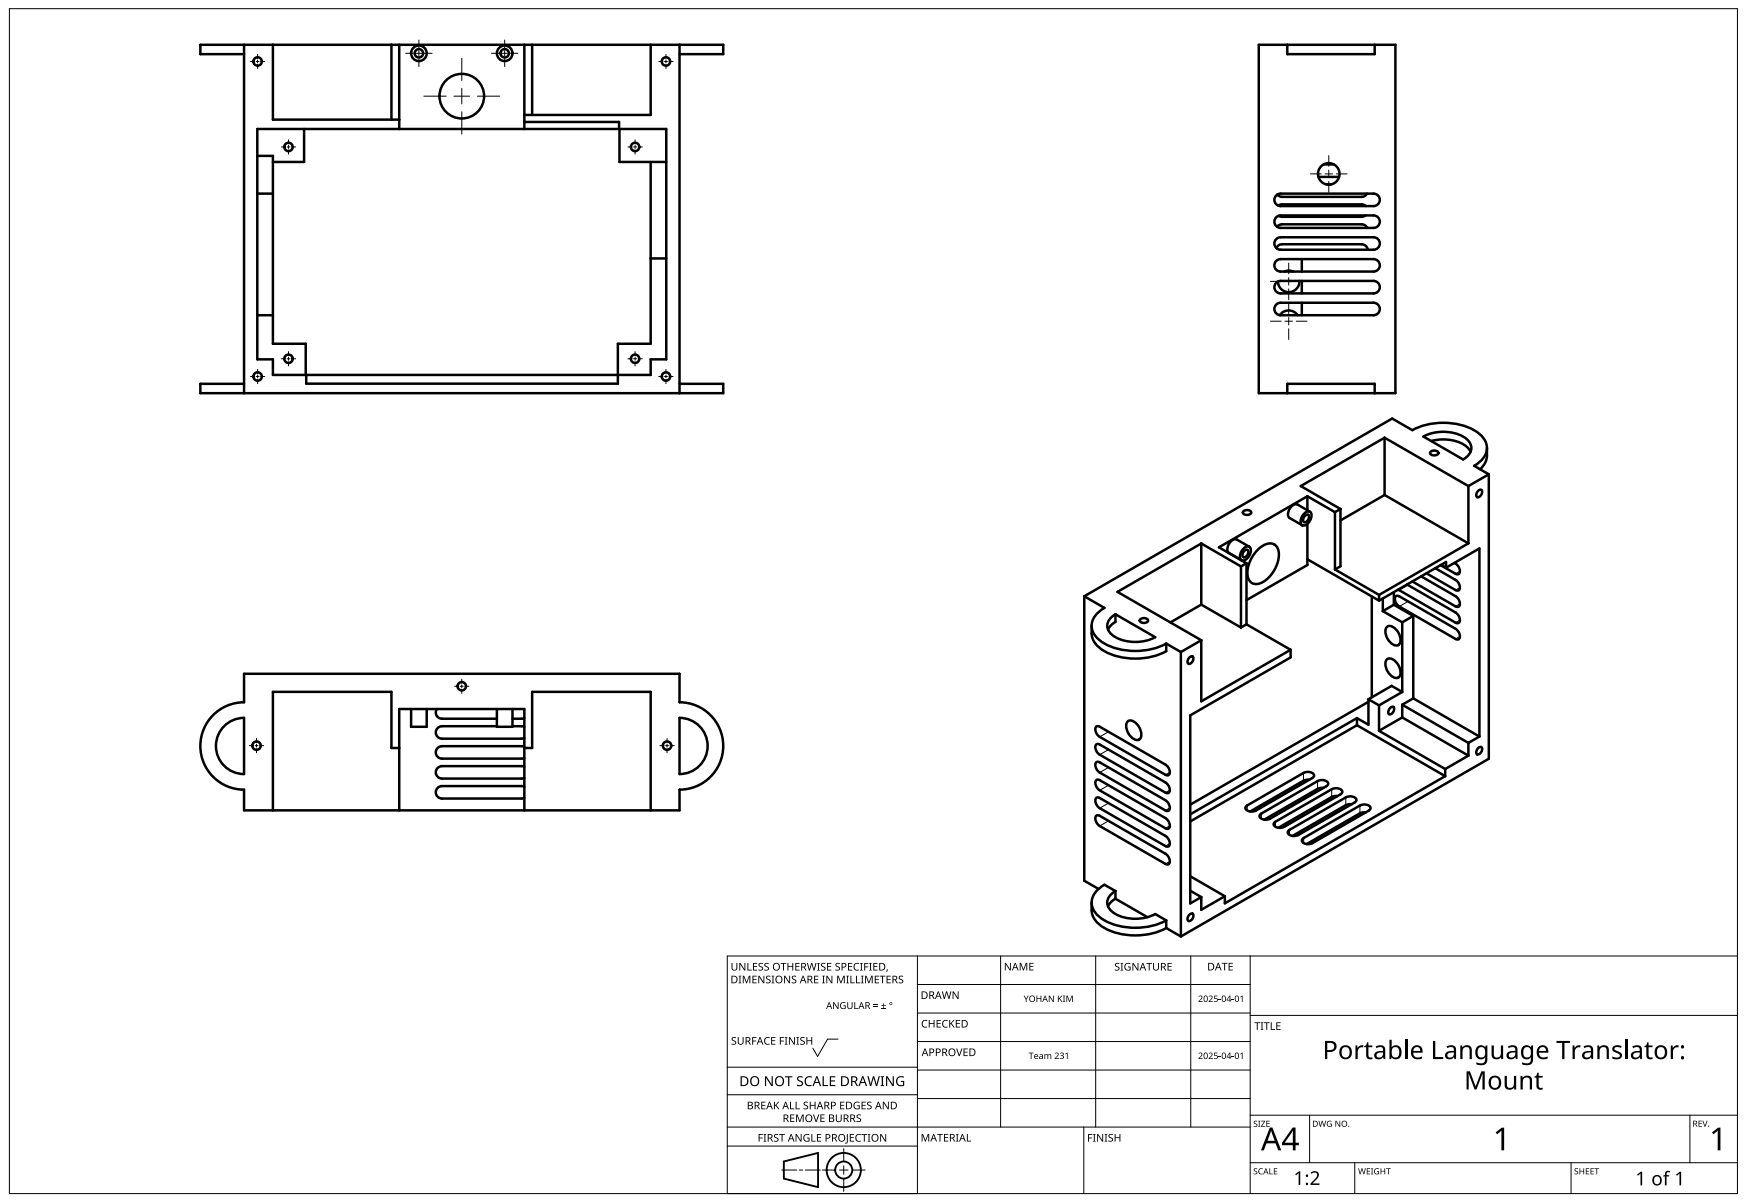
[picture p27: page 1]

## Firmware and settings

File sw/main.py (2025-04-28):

# everything.py
import sys
import cv2
import mediapipe as mp
import numpy as np
import tensorflow as tf
import shared
import time
import threading
import queue
import os
import sounddevice as sd
# from flask import Flask, request, jsonify
# from flask_cors import CORS
from gpiozero import Button
from TabularUI import MainWindow
from PyQt5.QtWidgets import QApplication, QMessageBox
from translator_device import TranslatorDevice  # Adjust the import path as needed
from shared import latest_frame


# ==================== ASL & SPEECH SETUP ====================
actions = np.array(["hello", "thank you", "nothing", "help", "yes", "bathroom"])

# Load the TFLite model
model_path = "/home/plt/plt_project/Portable-Language-Translator/model.tflite"
interpreter = tf.lite.Interpreter(model_path=model_path)
interpreter.allocate_tensors()
input_details = interpreter.get_input_details()
output_details = interpreter.get_output_details()

def tflite_predict(sequence):
    """Run TFLite inference on a given input sequence."""
    sequence = np.expand_dims(sequence, axis=0).astype(np.float32)
    interpreter.set_tensor(input_details[0]['index'], sequence)
    interpreter.invoke()
    return interpreter.get_tensor(output_details[0]['index'])[0]

# Mediapipe setup
mp_holistic = mp.solutions.holistic
mp_drawing = mp.solutions.drawing_utils
holistic = mp_holistic.Holistic(min_detection_confidence=0.5, min_tracking_confidence=0.5)

def mediapipe_detection(image, model):
    """Runs MediaPipe Holistic on a frame and returns the drawn image and results."""
    image_rgb = cv2.cvtColor(image, cv2.COLOR_BGR2RGB)
    image_rgb.flags.writeable = False
    results = model.process(image_rgb)
    image_rgb.flags.writeable = True
    drawn_frame = cv2.cvtColor(image_rgb, cv2.COLOR_RGB2BGR)
    return drawn_frame, results

def extract_keypoints(results):
    """Extract keypoints from MediaPipe Holistic results."""
    # Extract pose landmarks (33 landmarks * 4 values (x,y,z,visibility))
    pose = np.array([[res.x, res.y, res.z, res.visibility] for res in results.pose_landmarks.landmark]).flatten() if results.pose_landmarks else np.zeros(132)
    
    # Extract left hand landmarks (21 landmarks * 3 values (x,y,z))
    lh = np.array([[res.x, res.y, res.z] for res in results.left_hand_landmarks.landmark]).flatten() if results.left_hand_landmarks else np.zeros(63)
    
    # Extract right hand landmarks (21 landmarks * 3 values (x,y,z))
    rh = np.array([[res.x, res.y, res.z] for res in results.right_hand_landmarks.landmark]).flatten() if results.right_hand_landmarks else np.zeros(63)
    
    return np.concatenate([pose, lh, rh])

def draw_styled_landmarks(image, results):
    """Draw landmarks and connections for pose and hands."""
    # Draw pose connections
    mp_drawing.draw_landmarks(
        image, results.pose_landmarks, mp_holistic.POSE_CONNECTIONS,
        mp_drawing.DrawingSpec(color=(80,22,10), thickness=2, circle_radius=4),
        mp_drawing.DrawingSpec(color=(80,44,121), thickness=2, circle_radius=2)
    )
    # Draw left hand connections
    mp_drawing.draw_landmarks(
        image, results.left_hand_landmarks, mp_holistic.HAND_CONNECTIONS,
        mp_drawing.DrawingSpec(color=(121,22,76), thickness=2, circle_radius=4),
        mp_drawing.DrawingSpec(color=(121,44,250), thickness=2, circle_radius=2)
    )
    # Draw right hand connections
    mp_drawing.draw_landmarks(
        image, results.right_hand_landmarks, mp_holistic.HAND_CONNECTIONS,
        mp_drawing.DrawingSpec(color=(245,117,66), thickness=2, circle_radius=4),
        mp_drawing.DrawingSpec(color=(245,66,230), thickness=2, circle_radius=2)
    )

# Queues and threading for asynchronous inference
sequence_queue = queue.Queue(maxsize=5)
result_queue = queue.Queue(maxsize=5)
stop_thread = False

def inference_worker():
    """Processes sequences asynchronously in a separate thread."""
    while not stop_thread:
        try:
            sequence = sequence_queue.get(timeout=1)
            res = tflite_predict(sequence)
            predicted_action = np.argmax(res)
            result_queue.put((predicted_action, res[predicted_action]))
        except queue.Empty:
            continue

asl_thread = threading.Thread(target=inference_worker, daemon=True)
asl_thread.start()

# ==================== FLASK & TRANSLATOR SETUP ====================

translator_device = TranslatorDevice()

def speech_mode_logic():
    """Activate speech mode."""
    print("Switched to Speech Mode. Translator device is active and listening.")
    translator_device.vad_active = True
    translator_device.vad_active = False
    time.sleep(1)
    translator_device.vad_active = True
    translator_device.active = True
    

def asl_mode_logic():
    """Initialize ASL mode."""
    print("Switched to ASL Mode. Camera activated for gesture detection.")
    translator_device.active = False
    translator_device.vad_active = False
    shared.ui_mode = "CAMERA"

translator_thread = threading.Thread(target=translator_device.start, daemon=True)
translator_thread.start()
translator_device.translator_thread = translator_thread


# ==================== PHYSICAL BUTTON & VOLUME SETUP ====================
    
def set_volume(level):
    # Ensure level doesn't exceed 90%
    capped_level = min(90, max(0, level))
    os.system(f"amixer -D pulse sset Master {capped_level}%")

def increase_volume(step=5):
    current = get_volume()
    # Calculate new volume but don't exceed 90%
    new_volume = min(90, current + step)
    set_volume(new_volume)

def decrease_volume(step=5):
    current = get_volume()
    # Ensure volume doesn't go below 0
    new_volume = max(0, current - step)
    set_volume(new_volume)

def get_volume():
    result = os.popen("amixer -D pulse get Master").read()
    volume = int(result.split('[')[1].split('%')[0])
    return volume

# Adjust these pin numbers as needed
PIN_MODE = 4
PIN_UP = 17
PIN_DOWN = 27

# Global mode variable and camera handle (for ASL mode)
mode = "SPEECH"  # Initial mode
cap = None

def flush_audio_stream():
    # Open a temporary stream to read and discard frames
    with sd.InputStream(samplerate=translator_device.SAMPLE_RATE, 
                        channels=translator_device.NUM_CHANNELS, dtype='int16') as flush_stream:
        # Read and discard frames for 2 seconds
        flush_end = time.time() + 2
        while time.time() < flush_end:
            try:
                _ = flush_stream.read(int(translator_device.SAMPLE_RATE * (translator_device.FRAME_DURATION / 1000.0)))
            except Exception as e:
                pass

def change_mode():
    global mode, cap, sequence, predictions, sentence
    # Flush ASL buffers/queues
    while not sequence_queue.empty():
        sequence_queue.get_nowait()
    while not result_queue.empty():
        result_queue.get_nowait()
    sequence.clear()
    predictions.clear()
    sentence.clear()
    
    cv2.destroyAllWindows()
    if mode == "ASL":
        mode = "SPEECH"
        speech_mode_logic()
        if cap is not None:
            cap.release()
            cap = None      
        print("Mode changed to SPEECH")
        translator_device.reset()
        translator_device.active = True
        shared.ui_mode = "TEXT"
    else:
        mode = "ASL"
        with open(file_path, 'w') as file:
            pass  # clear the file contents
        asl_mode_logic()
        if cap is None:
            cap = cv2.VideoCapture(0)
        print("Mode changed to ASL")
        shared.ui_mode = "CAMERA"

    shared.mode = mode

def volume_up():
    print("Increased Volume")
    increase_volume()

def volume_down():
    print("Decreased Volume")
    decrease_volume()

button_mode = Button(PIN_MODE, pull_up=True, bounce_time=0.2)
button_up = Button(PIN_UP, pull_up=True, bounce_time=0.2)
button_down = Button(PIN_DOWN, pull_up=True, bounce_time=0.2)

button_mode.when_pressed = change_mode
button_up.when_pressed = volume_up
button_down.when_pressed = volume_down

# ==================== ASL PROCESSING (Non-UI) ====================

# Variables used in ASL processing
sequence = []
predictions = []
sentence = []
threshold = 0.9
last_detection_time = time.time()
frame_count = 0
start_time = time.time()
latest_frame = None
last_prediction_time = 0
min_prediction_interval = 0
HISTORY_LENGTH = 4  # Number of predictions to consider
MIN_CONSISTENT_PREDICTIONS = 3  # Minimum number of same predictions needed
prediction_history = []  # Store recent predictions

# hands_instance = mp_hands.Hands(min_detection_confidence=0.5, min_tracking_confidence=0.8)

def asl_processing_loop():
    nothing_count = 0
    current_prediction = ""
    global cap, sequence, predictions, sentence, last_detection_time, frame_count
    global start_time, latest_frame, last_prediction_time, prediction_history

    while True:
        if mode == "ASL":
            if cap is None:
                cap = cv2.VideoCapture(0)
                cap.set(cv2.CAP_PROP_FRAME_WIDTH, 640)  # Set a fixed width
                cap.set(cv2.CAP_PROP_FRAME_HEIGHT, 400) # Set a fixed height
            ret, frame = cap.read()
            if not ret:
                continue
            
            image = cv2.resize(frame, (640, 400)) # Resize the frame
            
            image, results = mediapipe_detection(frame, holistic)
            draw_styled_landmarks(image, results)

            # Draw current sentence at the top
            sentence_text = ' '.join(sentence)
            cv2.putText(image, f"Sentence: {sentence_text}", (10, 30),
                        cv2.FONT_HERSHEY_SIMPLEX, 1, (255, 255, 255), 2)
            

            shared.latest_frame = image.copy()  # Update this line to use the annotated image
            frame_count += 1
            
            keypoints = extract_keypoints(results)
            sequence.append(keypoints)
            sequence = sequence[-30:]

            # if len(sequence) >= 30 and frame_count % 2 == 0 and not sequence_queue.full():
            if len(sequence) >= 30 and not sequence_queue.full():
                sequence_queue.put_nowait(np.array(sequence[-30:]))

            if not result_queue.empty():
                predicted_action, confidence = result_queue.get_nowait()
                action_name = actions[predicted_action]
                current_time = time.time()
                time_since_last_prediction = current_time - last_prediction_time

                # Update current prediction display with more info
                current_prediction = f"{action_name} ({confidence:.2f})"

                prediction_history.append(action_name)
                prediction_history = prediction_history[-HISTORY_LENGTH:]

                if confidence > threshold:
                    prediction_counts = prediction_history.count(action_name)

                    if sentence and sentence[-1] == "thank you" and action_name == "yes":
                        # Skip this prediction, do not update last_prediction_time or clear history.
                        pass
                    elif action_name == "nothing":
                        nothing_count += 1
                        last_prediction_time = current_time
                    elif (time_since_last_prediction >= min_prediction_interval and 
                        prediction_counts >= MIN_CONSISTENT_PREDICTIONS):  # Removed length check
                        nothing_count = 0
                        if not sentence or action_name != sentence[-1]:
                            sentence.append(action_name)
                            last_prediction_time = current_time
                            prediction_history.clear()  

                # Trigger synthesis on consecutive "nothing" gestures
                if nothing_count >= 2 and any(word != "nothing" for word in sentence):
                    text_out = ' '.join(sentence)
                    translator_device.synthesize_speech(text_out, translator_device.base_language)
                    shared.ui_mode = "TEXT"

                    # Reset all tracking variables
                    sentence.clear()
                    sequence.clear()
                    predictions.clear()
                    prediction_history.clear()
                    nothing_count = 0
                    
                    with open(file_path, 'w') as file:
                        pass  # Clear file contents

                    # Handle audio transcription
                    translator_device.vad_active = True
                    transcript = translator_device.listen_and_save_transcription(
                        file_path="als_speech_audio_transcription.txt")
                    translator_device.vad_active = False

                    time.sleep(3)
                    with open(file_path, 'w') as file:
                        pass
                    shared.ui_mode = "CAMERA"

            time.sleep(0.03)
        else:
            # Speech mode handling
            if cap is not None:
                cap.release()
                cap = None
            shared.ui_mode = "TEXT"
            time.sleep(0.1)

asl_proc_thread = threading.Thread(target=asl_processing_loop, daemon=True)
asl_proc_thread.start()

# ==================== THREAD CLEANUP FUNCTION ====================
def cleanup():
    global stop_thread, cap
    print("Initiating cleanup...")
    stop_thread = True  # Signal all loops to exit
    # Release the camera if in use
    if cap is not None:
        cap.release()
    # Join threads
    asl_proc_thread.join()
    asl_thread.join()
    translator_thread.join()
    # flask_thread.join()
    print("Cleanup complete.")

# ==================== APPLICATION ENTRY POINT ====================

if __name__ == "__main__":
    file_path = "als_speech_audio_transcription.txt"  # This file is updated by the ASL processing thread
    with open(file_path, 'w') as file:
        pass  # clear the file contents

    app_qt = QApplication(sys.argv)
    window = MainWindow(file_path, translator_device)
    window.show()
    try:
        exit_code = app_qt.exec_()
    except KeyboardInterrupt:
        exit_code = 0
    finally:
        cleanup()
    sys.exit(exit_code)

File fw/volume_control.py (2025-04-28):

import os
import time

def set_volume(level):
    """Set volume level (0-100%)"""
    os.system(f"amixer -D pulse sset Master {level}%")

def increase_volume(step=5):
    """Increase volume by a step"""
    os.system(f"amixer -D pulse sset Master {step}%+")

def decrease_volume(step=5):
    """Decrease volume by a step"""
    os.system(f"amixer -D pulse sset Master {step}%-")

def get_volume():
    """Get current volume level"""
    result = os.popen("amixer -D pulse get Master").read()
    # Extract the volume percentage from the output
    volume = int(result.split('[')[1].split('%')[0])
    return volume

def adjust_volume():
    """Decrease volume until 0, then increase"""
    increasing = False
    while True:
        current_volume = get_volume()
        
        if increasing:
            if current_volume < 100:
                increase_volume(5)
            if current_volume == 100:
                increasing = False
        else:
            if current_volume > 0:
                decrease_volume(5)
            if current_volume == 0:
                increasing = True
        
        # Wait 5 seconds before adjusting volume again
        time.sleep(5)

if __name__ == "__main__":
    adjust_volume()
